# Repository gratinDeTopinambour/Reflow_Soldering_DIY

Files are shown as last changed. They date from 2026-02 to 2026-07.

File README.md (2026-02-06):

# Reflow Soldering DIY Controller

**Convert a standard consumer oven into a precise PCB reflow soldering station.**

This repository contains the complete electronics design, firmware, and mechanical files for a custom Reflow Oven Controller.The device is designed to precisely control a resistive heating element to follow the specific temperature profiles required for SMD soldering.

---

## 📂 Repository Structure

* **`Code/`**: Firmware source code for the STM32C0 microcontroller.
* **`Doc/`**: General project documentation and datasheets.
* **`Electronics/`**: Hardware design files, including the detailed technical rationale.
* **`3Dprint/`**: STL and CAD files for the controller enclosure.

---

## ⚡ System Overview

The controller operates as a closed-loop feedback system that regulates the temperature of a resistive heating element. 

### Key Technical Features
* **Power Control**: Designed for 220V / 50Hz mains up to **2400W** (12A design reference).
* **Switching Strategy**: Utilizes Zero-Crossing control to minimize EMI and power losses.
* **Galvanic Isolation**: Complete isolation between high-voltage AC and low-voltage logic via an Opto-TRIAC.
* **Microcontroller**: Powered by an **STM32C0 series** ARM Cortex-M0+.
* **User Interface**: Features an OLED display (128x64) and a 6-button navigation cluster.
* **Thermal Sensing**: Uses a glass-encapsulated NTC thermistor rated up to **300°C**.

---

## 🛠️ Hardware Specifications

The hardware design prioritizes low-cost, hand-solderable components and robust thermal management.

### Power Stage
| Component | Selection | Rationale |
| :--- | :--- | :--- |
| **TRIAC** | BTA16-600CW | 16A max current, snubberless design  |
| **Opto-TRIAC** | MOC3063M | Zero-crossing detection and safe isolation  |
| **Heatsink** | Boyd 530002B02500G | $2.6^{\circ}C/W$ resistance to handle ~13W dissipation  |

### Logic & Power
* **Input**: USB-C (5V).
* **Regulation**: L1117S33 LDO (SOT-223) provides a stable 3.3V rail for the MCU.
* **Optimization**: The temperature sensor uses an optimized $1.8k\Omega$ bridge resistor to maximize ADC voltage swing between $60^{\circ}C$ and $260^{\circ}C$.

---

## 🚀 Installation & Safety

### ⚠️ WARNING: High Voltage
This project involves **220V AC Mains**. Fatal injury or fire can occur if handled incorrectly. 
* Always ensure the device is unplugged before touching the electronics.
* Ensure the TRIAC heatsink is properly mounted as temperatures can reach $\approx 100^{\circ}C$ during operation.

### Setup
1. **Assembly**: Refer to the schematics in `Electronics/`. The design uses TSSOP-20 and SOT-223 packages for easy manual assembly.
2. **Firmware**: Flash the STM32C0 via the SWD interface pins (PA14/PA15).
3. **Calibration**: The system is tuned for a standard NTC thermistor (NRBG105F3950B1F).

---

## 👤 Author
**Valentin LEFEBVRE** (@topinambour)  
*Document Date: 06/02/2026*

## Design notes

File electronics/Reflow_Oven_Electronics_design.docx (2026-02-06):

Reflow-Oven Controller

Electronics design

LEFEBVRE Valentin, @topinambour

06/02/2026

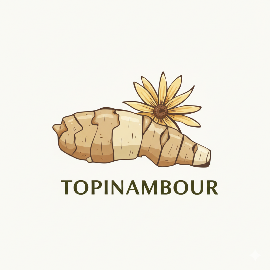
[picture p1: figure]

# 1 Introduction

The purpose of this document is to detail the electronics design, component selection, and calculations for a custom Reflow Oven Controller board.

This device is designed to convert a standard consumer oven into a PCB reflow soldering station. The main objective is to precisely control the oven's heating element to follow a specific temperature profile required for soldering surface-mount components. The controller manages the AC mains power to the heater, monitors the internal temperature in real-time, and provides a user interface for operation and status monitoring.

# 2 System Overview

## 2.1 Functional Description

The Reflow Oven Controller operates as a closed-loop feedback system that regulates the temperature of a resistive heating element.

Power Control: The system controls the AC mains power (220V, 50Hz) delivered to the oven's heater. Instead of complex phase-angle control, the system utilizes a simple on/off control scheme (Zero-Crossing), which is sufficient due to the high thermal inertia of the oven.

Isolation & Safety: To ensure safety and protect the low-voltage logic, a TRIAC is used to switch the load, driven by an Opto-TRIAC to provide galvanic isolation between the microcontroller and the high-voltage mains.

Central Processing: An STM32C0 series microcontroller acts as the brain of the system. It reads the temperature sensor, processes the control logic, drives the solid-state switch, and manages the user interface.

Sensing: Temperature monitoring is achieved using a glass-encapsulated NTC thermistor capable of withstanding high temperatures (up to 300°C) placed inside the oven.

User Interface: The operator interacts with the device through an OLED display and a set of push-buttons, allowing for profile selection and visual feedback during the reflow process.

Power Supply: The logic circuitry is powered via a USB-C connector (5V), which is regulated down to 3.3V to supply the microcontroller and peripherals.

## 2.2 Block Diagram

Oven

AC Power command

STM32C0

Temp sensor

Power input

User Interface

Oled display

Push button

Main AC

## 2.3 Main Design Requirements

The hardware design is driven by the following key electrical and environmental requirements:

AC Mains Compatibility: The device must operate on a 220V / 50Hz mains supply.

Load Capacity: The power stage must handle ovens rated up to 2400 W, requiring a design reference current of approximately 12 A.

Thermal Environment: Electronic components, particularly the power stage, must be rated to operate reliably within an enclosure ambient temperature of 50°C.

Galvanic Isolation: There must be complete isolation between the AC mains and the user-accessible logic/interface section.

EMI Reduction: Switching must occur at the AC zero-crossing point to minimize electromagnetic interference (EMI) and power losses.

Low Voltage Supply: The board must be powered by a standard USB-C connection (5V) and internally regulated to 3.3V for logic operation.

Cost & Assembly: The design prioritizes low-cost components and packages suitable for hand-soldering (e.g., TSSOP-20 for the MCU, SOT-223 for the LDO).

Temperature Range: The sensing subsystem must accurately measure temperatures from ambient (~15°C) up to the reflow peak of 260°C.

# 3 Heater power control

The main objective is to switch the oven on and off for use as a reflow oven. A TRIAC will be used to control the mains power to the oven, and an opto‑TRIAC driver will provide galvanic isolation between the microcontroller and the AC mains. Due to the thermal inertia of the oven, precise phase-angle control is not required. Simple on/off control is sufficient. To minimize unnecessary power losses and reduce EMI, a zero‑crossing opto‑TRIAC is used (at 50 Hz, the mains voltage crosses zero every 10 ms).

We will design the board for ovens up to 2400 W on a 220 V / 50 Hz mains supply.

The corresponding RMS current is:
- (2400 W)/(220V) ≈ 10.9 A
- Adding a 5% margin gives 11.45 A, so we will use 12 A as the design reference current.

## 3.1 Triac

To select a suitable TRIAC, we use ST’s ACS/TRIAC selection and simulation tool: https://eds.st.com/acswitch/#/

The simulator is configured with the following parameters:
- Nominal input voltage: 230 V
- Output RMS current: 12 A
- Load type: Heater
- Gate control: Isolated, phototriac

The Simulator give us the following schematics:

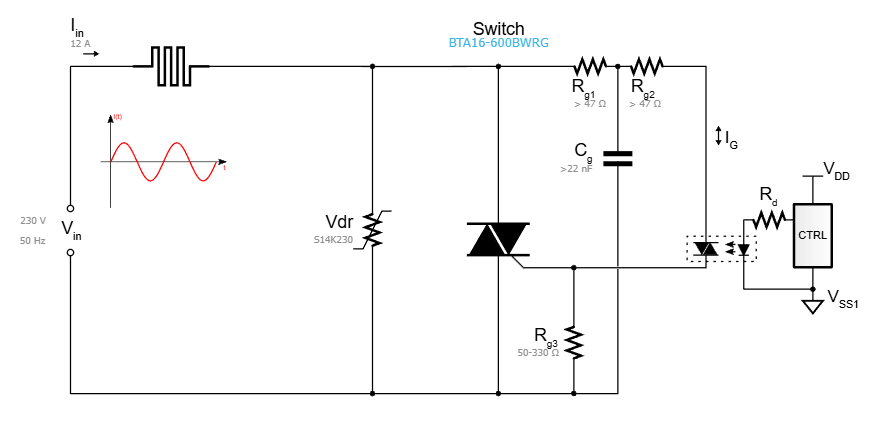
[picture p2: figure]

Figure 1: Heater Power Control ST Schematics

From the list of TRIACs suggested by ST, we will select the device with the lowest power dissipation. However, before making a final choice, we must refine the simulation parameters: 12 ARMS is too high to handle without an adequate heatsink.

In the ST simulator, under the heatsink selection options, we choose “Case in Environment” and set the environment temperature to 50 °C (estimated internal temperature inside a closed enclosure).

With these conditions, the BTA16-600CW appears to be a good candidate:
- IRMS max: 16 A
- VDRM/ VRRM: 600 V

From the datasheet, in Figure 2: “Maximum power dissipation versus on‑state RMS current (full cycle)”, the expected power dissipation at 12 ARMS is approximately 13W.

## 3.2 Heatsink

To dissipate these 13 W, we need a heatsink such that the total thermal resistance keeps the TRIAC junction below its maximum temperature. The required heatsink thermal resistance Rth(sa) can be calculated with:

P=((Tjmax-Ta))/(Rth(jc)+Rth(cs)+Rth(sa))

From the datasheet and our assumptions:
-Rth(jc) = 2.1°C/W
-Tjmax = 125°C.
-Ta = 50°C (temperature inside the box)
-Rth(cs) = 0.5°C/W

Rth(sa)=((Tjmax-Ta))/P- Rth(jc)-Rth(cs)= ((125-50))/13- 2.1-0.5=3.17°C/W

To safely dissipate 13 W at a 50°C ambient temperature inside the enclosure, we will need a heatsink with a thermal resistance of 3.17 °C/W or lower (the lower the value, the more effective the heatsink).

We will choose Heatsink 530002B02500G from BOYD for our design

The heatsink 530002B02500G from BOYD has a thermal resistance of 2.6 °C/W. At 14 W, it will cause a temperature rise of about 50°C (see thermal graph from datasheet) above the ambient temperature inside the box. With Ta = 50 °C, the heatsink temperature will be approximately 100°C, and the TRIAC junction will remain below its maximum 125 °C limit, ensuring safe operation.

## 3.3 OptoTriac

The opto‑triac is driven directly by the STM32 GPIO (3.3 V maximum I/O voltage).
A zero‑crossing device is required for reliable operation on 220 V rms mains.
The MOC3063, a widely used zero‑crossing opto‑triac, satisfies these requirements and is used in this design.

Emitter side
- Forward voltage (Vf) minimum: 0.7 V at Ift ≈ 0.1 mA
- Series resistor: 150 Ω from the 3.3 V GPIO to the LED

Power dissipation in the LED:
Pemitter = ((3.3 – Vf_min)²)/150= ((3.3 – 0.7)²)/150 ≈ 48 mW

Assuming an ambient temperature Ta = 50 °C and an LED thermal resistance giving a power‑to‑temperature factor of 0.00141 W/°C, the junction temperature is:
Tj_(emitter) = Ta + (Pemitter)/0.00141=50°C+ 0.048/0.00141=84°C

Detector side
The driven power triac is a BTA16CW, with a maximum gate trigger current of 25 mA.
At this current, the voltage across the opto‑triac output is:
Vtm(max at 25 mA) = 1.8 V

Power dissipation in the detector:
Pdetector = Vtm × Igate =1.8 V × 25 mA ≈ 45 mW

With an ambient temperature Ta = 50 °C and a power‑to‑temperature factor of 0.00176 W/°C for the detector section, the junction temperature is:

Tj_(detector) = Ta + (Pdetector)/0.00176=50°C+ 0.045/0.00176=76°C

Both the emitter and detector junction temperatures remain well within the safe operating range for the MOC3063 under the specified conditions.

## 3.4 Passive Components

The BTA16 is a snubberless Triac, and the load will not produce enough noise to cause issues. We can therefore simplify the design as follows.

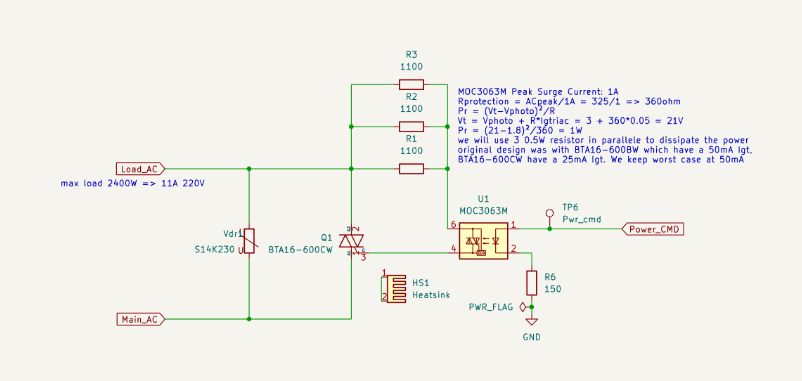
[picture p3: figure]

The resistor between the triac and the optotriac is designed to protect the optotriac from current surges. The MOC3063M can withstand up to 1 A of peak current.

We calculate the minimum resistance as:

R=(230*√2)/1=325ohm

We therefore need R > 325x1,05 = 341ohm. The closest standard value in the E24 series is 360ohm

Now we calculate the maximum power dissipated in the resistor:

Vtriacmax = R*Igatemax + Vphotomax = 360*0,025 + 3 = 12V

Pres = ((Vtriacmax – Vphotomin )²)/R=((12-0)²)/360= 0.4W

To be on the safe side. We will use three 1.1 kΩ, 0.5 W resistors in parallel to dissipate the power.

Recomputing for the worst-case scenario:

Iphotomax=(230*√2)/((R*0,95)/3)=0,934mA

Presmax= (Vtriacmax²)/((R*0,95)/3)=0.41W

This satisfies:

Iphoto < 1A

Pres/3 <0,5W

So, three 1.1 kΩ, 0.5 W resistors in parallel are sufficient for this design.

## 3.5 Command resistor

The STM32 microcontroller GPIO outputs 3.3 V with a maximum current of 20 mA.

The MOC3063M LED has a maximum trigger current of 5 mA.

Based on Figure 3: LED Forward Voltage vs. Forward Current from MOC3063M datasheet

- For 5 mA Vfmax = 1.25V

- For 20 mA, Vfmin = 1.1V

Series resistor calculation:

Rmin=(1,1V)/(20mA)=55ohm

Rmax=(1,25V)/(5mA)=250ohm

We will use R = 150ohm, as this value is already used multiple times in our design.

With R = 150ohm, the worst‑case current is:

If=(3,3V*0,95-1,5V)/(150*1,05)=10mA>5mA

This ensures reliable triggering of the MOC3063M while staying within the STM32 GPIO current capability.

# 4 Microcontroller

## 4.1 Microcontroller selection

The microcontroller is responsible for managing the user interface, temperature measurement, and control of the oven power stage. The following constraints and requirements drove the selection:

Electrical and System Constraints

Supply voltage:
- The board is powered from a USB‑C connector.
- A linear regulator (LDO) is used to stabilize the input voltage.
- The microcontroller must operate from a regulated supply below 5 V (nominally 3.3 V).

Required peripherals and I/Os:
- 6 digital inputs for the user interface:
- 1 I²C interface for the OLED display
- 1 analog input for temperature measurement
- 1 digital output for power control

In summary, the microcontroller must provide at least:
- VCC < 5 V
- 6 GPIO inputs
- 1 GPIO output
- 1 I²C bus
- 1 ADC channel

Package and Assembly Constraints

Since the board is intended to be assembled without a reflow oven in the first iterations, ease of hand‑soldering is a key criterion:

Preferred package: TSSOP, which offers:
- Sufficient pin pitch for manual soldering
- Good balance between pin count and PCB area

Minimum pin count: at least 10 pins are required (6 inputs + 1 output + I²C + analog input + supply/ground), so TSSOP‑8 is not suitable.

Given these constraints, TSSOP‑20 devices are a good fit: they are widely available, easy to solder by hand, and provide sufficient I/O and peripherals.

Technology and Cost Considerations

Several MCU families were considered:

Arduino‑style MCUs (e.g., ATmega328P):
- Operate at 5 V and are well known.
- However, they are relatively expensive for this application.

ESP32 / Wi‑Fi‑capable MCUs:
- Provide significantly more performance and peripherals than needed.
- Higher power consumption and unnecessary complexity for this design.

STM32 family (32‑bit ARM Cortex‑M):
- Low cost, especially in the low‑end series.
- Good availability of small packages such as TSSOP‑20.
- Familiar toolchain and ecosystem from previous projects.

Given prior experience with STM32 and their cost/performance ratio, an STM32 device was chosen.

Candidate Microcontrollers

Two pin‑compatible STM32 devices were identified as suitable candidates:
- STM32C011F6P6
- STM32C031F6P6

Common features relevant to this design:
- Supply voltage compatible with the regulated USB‑derived rail (< 5 V).
- TSSOP‑20 package, suitable for hand soldering.
- Sufficient GPIOs to handle:
- 6 push‑button inputs
- 1 digital output for MOC3063M control
- I²C interface for the OLED display
- 1 ADC channel for the thermistor

The main difference between the two devices is available RAM:
- STM32C011F6P6: 6 KB RAM
- STM32C031F6P6: 12 KB RAM

The OLED display has a resolution of 128 × 64 pixels, corresponding to 8192 bits (1024 bytes) for a full framebuffer. Depending on the graphics library and implementation, a significant portion of RAM may be needed to store display buffers, fonts, and temporary data structures.

Because the firmware will be developed after the hardware design, the exact RAM requirement is not fully defined at this stage. To keep flexibility the PCB will be designed to accept either STM32C011F6P6 or STM32C031F6P6 (same pinout/package).

During firmware development, memory usage will be evaluated:

- If 6 KB RAM is sufficient, the STM32C011 can be used, minimizing cost.
- If additional memory is required (e.g., for more complex UI or buffering), the STM32C031 will be assembled instead.

Final Choice

The design supports both STM32C011F6P6 and STM32C031F6P6 in TSSOP‑20 package. The STM32C0 series meets all functional, electrical, and packaging constraints while remaining low cost and easy to assemble by hand. The final MCU variant (C011 vs. C031) will be selected based on actual RAM requirements determined during firmware development.

## 4.2 STM32C0 implementation

The microcontroller used is from the STM32C0 series in a TSSOP‑20 package. Pin usage follows the recommendations from the STM32C0 datasheet and is tailored to the application’s I/O, analog, and communication requirements.

Reserved and Special‑Function Pins
PF2 – NRST:
- Used as the global reset input for the MCU.
- A 10 kΩ pull‑up resistor to VCC is added to prevent unintended resets due to noise.
- A momentary push‑button connects NRST to GND to allow manual reset.
- A 100 nF capacitor is connected between NRST and GND, as recommended in the datasheet, to improve noise immunity.

PA14 – BOOT0:
- Used to select the boot mode (normal user flash vs. system bootloader).
- The default state is normal user flash boot:
- A 10 kΩ pull‑down resistor to GND ensures BOOT0 is low during normal operation.
- A momentary push‑button connects BOOT0 to VCC when pressed, allowing the MCU to enter the bootloader if required.
- A 100 nF capacitor is placed between BOOT0 and GND as recommended, to avoid spurious boot mode changes due to noise.

PA14 / PA15 – SWD Interface:
- PA14: SWCLK
- PA15: SWDIO
- These pins are routed to a standard ST‑LINK SWD connector for programming and debugging.
- No other functions are assigned to these pins to ensure reliable SWD communication.

PC14 / PC15 – Oscillator Pins:
- Dedicated to an external low‑speed or high‑speed crystal/oscillator.
- For this design, no external oscillator is used. The internal oscillator of the STM32C0 is sufficient for the required timing accuracy.
- PC14 and PC15 are therefore left unconnected.

Functional Pin Mapping

The remaining pins are assigned as follows:
I²C interface (OLED display)
- PB6: I2C SCL
- PB7: I2C SDA

User push buttons (digital inputs)
- PA2: “Return” button
- PA3: “Valid” button
- PA4 – PA7: 4 directional buttons (cross pattern)

Temperature measurement (analog input)
- PA0: ADC input for the NTC thermistor.

Oven power control (digital output)
- PA8: Digital output driving the control input of the MOC3063M optotriac driver.

Status LEDs (digital outputs)
- PA9/PA10: LED output

This pin mapping was defined in STM32CubeIDE, ensuring all required peripherals (I²C, ADC, GPIO) are properly configured and that there are spare I/Os for debugging or future extensions.

Power Supply Decoupling

The MCU is powered from the regulated VCC rail derived from the USB‑C input via an LDO. According to the STM32C0 datasheet, local decoupling capacitors (100nF and 4.7uF) are required between VCC and GND (at the MCU pins):

# 5 Temperature sensor

## 5.1 Component selection

To monitor the temperature inside the oven, we considered two options:

Thermocouple
Thermocouples offer a very wide measurement range (approximately −200°C to 1000°C) and good accuracy, but they require dedicated front‑end electronics (amplifier, cold‑junction compensation, ADC), which increases both cost and design complexity.

Thermistor
Standard NTC thermistors are typically rated up to about 150°C, but glass‑encapsulated thermistors can operate up to roughly 300°C. They are inexpensive and can be read with a simple resistor divider connected to the microcontroller’s ADC input.

Given the target reflow profile (from ambient ≈15°C up to 260°C), and in order to minimize cost and complexity, we selected a glass NTC thermistor, reference NRBG105F3950B1F, specified from −40°C to 300°C.

Resistor Divider Design
The thermistor is used in a voltage divider to generate a temperature‑dependent voltage for the STM32 ADC:
Supply voltage: 3.3 V
One fixed resistor R
The NTC thermistor NRBG105F3950B1F

We want to choose R so that the ADC sees the widest possible voltage variation over the most relevant temperature range, which in our case is 60°C to 260°C (the useful reflow control region).

Vt=3.3V*R/(Rth1+R)

From the datasheet:
at 60°C Rth1 =24.75kohm
at 260°C Rth1 = 145ohm
we want |Vt60°C – Vt260°C| as high as possible

Max|Vt60-Vt260|=Max|3.3*R/(Rth60+R)-3.3*R/(Rth260+R)|

Max|(R(Rth260+R)-R(Rth60+R))/((Rth60+R)(Rth260+R))|=Max|(-R*Rth60)/(R^2 +(Rth60+Rth260)R+Rth60*Rth260)|

We look after the derivate in zero.

(-(Rth60-Rth260)*(R^2 +(Rth60+Rth260)R+Rth60*Rth260)+R24605(2R+(Rth60+Rth260)))/((R^2 +(Rth60+Rth260)R+Rth60*Rth260)^2)

(Rth60-Rth260)R^2 -(Rth60-Rth260)*Rth60*Rth260=0

R^2 =((Rth60-Rth260)*Rth60*Rth260)/((Rth60-Rth260))=Rth60*Rth260

R= √(Rth60*Rth260)=√3588750=1894ohm

From the optimization, the ideal bridge resistor value is approximately 1.894 kΩ. We will use a standard 1.80 kΩ, 0.1% resistor, which is the closest commonly available value.

At 60°C Vt = 0.22V

At 260°C Vt = 3.05V

This provides a large voltage swing at the STM32 ADC input.

# 6 User interface

The user interface includes:
- 6 push-buttons:
- 4 directional buttons (Up, Down, Left, Right)
- 1 “Valid” button
- 1 “Return” button
- 1 OLED display (I²C, 3.3 V)
- 2 status LEDs (Red and Green)

Buttons:
- Each button is connected between an STM32 GPIO and GND.
- Internal pull-up resistors of the STM32 are used.
- Logic: button released = logic high, button pressed = logic low.
- No external pull-up resistors are required.

OLED Display:
- Powered by 3.3 V from the on-board LDO.
- Connected to the STM32 via I²C (SCL, SDA).
- I²C pull-ups are configured inside the STM32.

Status LEDs:
- 2 LEDs (Red, Green), each in series with a 150 Ω resistor.
- Driven directly from STM32 GPIOs (no transistor needed).
- Current per LED is limited to about 10 mA, within STM32 GPIO limits (80 mA total).

# 7 Power regulator

This design uses a USB‑C connector as the main power input. To operate USB‑C in a simple “default power” sink mode (5 V supply), each CC pin must be pulled down to ground. We therefore connect a 5.1 kΩ (1%) resistor from:
- CC1 to GND
- CC2 to GND

The system logic operates at 3.3 V. Since the maximum current consumption is below 300 mA, a linear regulator (LDO) provides a simpler and adequate solution compared to a switching regulator (SMPS).

We selected the L1117S33 3.3 V LDO, commonly used on STM32 evaluation boards. Key characteristics:
- Input voltage: up to 15 V
- Fixed output: 3.3 V
- Typical dropout voltage: ~1 V
- Maximum output current: up to 800 mA

We use the SOT‑223 package because it is relatively easy to solder, it has a compact footprint and it can dissipate the required power with an appropriate copper thermal pad.

For the worst‑case calculation, we assume:
- Input voltage (including tolerance): 5 V × 1.05 = 5.25 V
- Output voltage (including tolerance): 3.235 V (worst‑case lower bound)
- Maximum load current: 300 mA

The power dissipated by the LDO is:

P= (5V*1.05-3.235V)*0.3A = 0.6W

Given the junction‑to‑ambient thermal resistance Rtja of 110 °C/W for the SOT‑223 package:

Tmax = Ta + Rtja*P = 50 + 110*0.6 = 116°C

With an ambient temperature of 50 °C, the junction temperature is estimated at about 116 °C, which remains below the maximum junction temperature Tjmax 125°C.

According to application note AN044_EN (Figure 11), a SOT‑223 package mounted on a PCB with a 100 mm² thermal pad can dissipate up to approximately 0.7 W. Our PCB layout includes a copper thermal pad larger than 100 mm², to maximize heat dissipation and provide additional safety margin.

The L1117 datasheet recommends:
- A 10 µF capacitor between the input pin and GND
- A 10 µF capacitor between the output pin and GND

These capacitors are placed as close as possible to the LDO pins to ensure stability and reduce noise on the 3.3 V rail.

A power indicator LED is connected between the 3.3 V output and GND through a 150 Ω series resistor. This LED provides a visual indication that the board is correctly powered and that the 3.3 V rail is present.

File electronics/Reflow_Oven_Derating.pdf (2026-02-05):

Reference | Value | Footprint | part | datasheet | Valid | Current (A) | Max Current (A) | Current_valid | Voltage (V) | Max Voltage (V) | Voltage_Valid | Power (W) | Max Power (W) | Power_valid | Temperature | Max temperature | Temp_valid
C1 100nF Capacitor_SMD:C_0805_2012Metric_Pad1.18x1.45mm_HandSolder C0805C104K5RACTU KEM_C1002_X7R_SMD.pdf | OK | | 3,365 50 | OK | | 50 125 | OK
C2 100nF Capacitor_SMD:C_0805_2012Metric_Pad1.18x1.45mm_HandSolder C0805C104K5RACTU KEM_C1002_X7R_SMD.pdf | OK | | 3,365 50 | OK | | 50 125 | OK
C3 100nF Capacitor_SMD:C_0805_2012Metric_Pad1.18x1.45mm_HandSolder C0805C104K5RACTU KEM_C1002_X7R_SMD.pdf | OK | | 3,365 50 | OK | | 50 125 | OK
C4 4.7uF Capacitor_SMD:C_0805_2012Metric_Pad1.18x1.45mm_HandSolder C0805C475K3RACTU KEM_C1002_X7R_SMD.pdf | OK | | 3,365 25 | OK | | 50 125 | OK
C5 10uF Capacitor_SMD:C_0805_2012Metric_Pad1.18x1.45mm_HandSolder C0805C106K3PACTU KEM_C1006_X5R_SMD.pdf | OK | | 5,25 25 | OK | | 50 85 | OK
C6 10uF Capacitor_SMD:C_0805_2012Metric_Pad1.18x1.45mm_HandSolder C0805C106K3PACTU KEM_C1006_X5R_SMD.pdf | OK | | 3,365 25 | OK | | 50 85 | OK
C7 100nF Capacitor_SMD:C_0805_2012Metric_Pad1.18x1.45mm_HandSolder C0805C104K5RACTU KEM_C1002_X7R_SMD.pdf | OK | | 3,365 50 | OK | | 50 125 | OK
D1 RED_LED LED_THT:LED_D5.0mm | OK
D2 GREEN_LED LED_THT:LED_D5.0mm | OK
QTLP650C4TR/FC15-DSE-0031723-QTLP650C4TR-FC15-D3 POWER_LED LED_SMD:LED_1206_3216Metric_Pad1.42x1.75mm_HandSolder 21SYGC/S530-E2/TR8 21SYGC-S530-E2-TR8 -V1.pdf | OK | 0,011212121 0,015 | OK | 3,365 5 | OK | 0,037728788 0,06 | OK | 50 85 | OK
HS1 HEAT_SINK 530002B02500G 530002B02500G Boyd-Board-Level-Heatsinks-Catalog.pdf | OK | | | | | | | 100 150 | OK
HP HEAT_PASTE -TC3-1G TC3-1G.pdf | OK | | | | | | | 100 150 | OK
J1 Conn_01x04_Pin Connector_PinHeader_2.54mm:PinHeader_1x04_P2.54mm_Vertical | OK
J2 OLED_Display Connector_PinHeader_2.54mm:PinHeader_1x04_P2.54mm_Vertical oled display ruizhi 0.96 OLED_096.pdf | OK | | | 3,365 5,2 | OK | | | 50 80 | OK
J3 USB_C_Receptacle_PowerOnly_6P Connector_USB:USB_C_Receptacle_GCT_USB4125-xx-x-0190_6P_TopMnt_Horizontal USB4125-GF-A usb4125-spec.pdf | OK | 0,80207962 3 | OK | 5,25 48 | OK | | | 50 85 | OK
Q1 BTA16-600CW Package_TO_SOT_THT:TO-220-3_Vertical BTA16-600CWRG bta16.pdf | OK | 12 16 | OK | 325,2691193 600 | OK | 13 14,42307692 | OK | 117,6 125 | OK
R1 1100ohm Resistor_THT:R_Axial_DIN0309_L9.0mm_D3.2mm_P12.70mm_Horizontal CFR-50JB-52-1K1 YAGEO-CFR_DATASHEET.pdf | OK | | | 230 300 | OK | 0,308611111 0,5 | OK | 50 70 | OK
R2 1100ohm Resistor_THT:R_Axial_DIN0309_L9.0mm_D3.2mm_P12.70mm_Horizontal CFR-50JB-52-1K1 YAGEO-CFR_DATASHEET.pdf | OK | | | 230 300 | OK | 0,308611111 0,5 | OK | 50 70 | OK
R3 1100ohm Resistor_THT:R_Axial_DIN0309_L9.0mm_D3.2mm_P12.70mm_Horizontal CFR-50JB-52-1K1 YAGEO-CFR_DATASHEET.pdf | OK | | | 230 300 | OK | 0,308611111 0,5 | OK | 50 70 | OK
R4 1800ohm Resistor_SMD:R_0805_2012Metric_Pad1.20x1.40mm_HandSolder ERA-6AEB182V R1800_panasonic.pdf | OK | | | 3,365 100 | OK | 0,006296978 0,125 | OK | 50 85 | OK
R5 150ohm Resistor_SMD:R_0805_2012Metric_Pad1.20x1.40mm_HandSolder CRCW0805150RFKEA resistor_vishay.pdf | OK | | | 3,365 150 | OK | 0,076250673 0,25 | OK | 50 70 | OK
R6 150ohm Resistor_SMD:R_0805_2012Metric_Pad1.20x1.40mm_HandSolder CRCW0805150RFKEA resistor_vishay.pdf | OK | | | 3,365 150 | OK | 0,076250673 0,25 | OK | 50 70 | OK
R7 150ohm Resistor_SMD:R_0805_2012Metric_Pad1.20x1.40mm_HandSolder CRCW0805150RFKEA resistor_vishay.pdf | OK | | | 3,365 150 | OK | 0,076250673 0,25 | OK | 50 70 | OK
R12 150ohm Resistor_SMD:R_0805_2012Metric_Pad1.20x1.40mm_HandSolder CRCW0805150RFKEA resistor_vishay.pdf | OK | | | 3,365 150 | OK | 0,076250673 0,25 | OK | 50 70 | OK
R8 10kohm Resistor_SMD:R_0805_2012Metric_Pad1.20x1.40mm_HandSolder CRCW080510K0FKEA resistor_vishay.pdf | OK | | | 3,365 150 | OK | 0,00114376 0,25 | OK | 50 70 | OK
R9 10kohm Resistor_SMD:R_0805_2012Metric_Pad1.20x1.40mm_HandSolder CRCW080510K0FKEA resistor_vishay.pdf | OK | | | 3,365 150 | OK | 0,00114376 0,25 | OK | 50 70 | OK
R10 5.1kohm Resistor_SMD:R_0805_2012Metric_Pad1.20x1.40mm_HandSolder CRCW08055K10FKEA resistor_vishay.pdf | OK | | | 5,25 150 | OK | 0,005459002 0,25 | OK | 50 70 | OK
R11 5.1kohm Resistor_SMD:R_0805_2012Metric_Pad1.20x1.40mm_HandSolder CRCW08055K10FKEA resistor_vishay.pdf | OK | | | 5,25 150 | OK | 0,005459002 0,25 | OK | 50 70 | OK
SW1 Valid Button_Switch_THT:SW_PUSH_6mm_H5mm | OK
SW2 Up Button_Switch_THT:SW_PUSH_6mm_H5mm | OK
SW3 Down Button_Switch_THT:SW_PUSH_6mm_H5mm | OK
SW4 Left Button_Switch_THT:SW_PUSH_6mm_H5mm | OK
SW5 Right Button_Switch_THT:SW_PUSH_6mm_H5mm | OK
SW6 return Button_Switch_THT:SW_PUSH_6mm_H5mm | OK
SW7 NRST Button_Switch_THT:SW_PUSH_6mm_H5mm | OK
SW8 BOOT0 Button_Switch_THT:SW_PUSH_6mm_H5mm | OK
eaton-nrbg-glass-sealed-radial-lead-ntc-TH1 Thermistor_NTC Resistor_THT:R_Axial_DIN0204_L3.6mm_D1.6mm_P2.54mm_Vertical NRBG105F3950B1F thermistor-datasheet-elx1105-en.pdf | OK | | | 3,365 50 | OK | 0,000233092 0,032 | OK | 260 300 | OK
U1_emitter MOC3063M Package_DIP:DIP-6_W7.62mm_LongPads MOC3063M MOC3163M-D.pdf | OK | 0,017946128 0,06 | OK | 3,365 6 | OK | 0,017946128 0,04935 | OK | 62,72775032 100 | OK
U1_detector MOC3063M Package_DIP:DIP-6_W7.62mm_LongPads MOC3063M MOC3163M-D.pdf | OK | 0,89605818 1 | OK | 325,2691193 600 | OK | 0,045 0,0616 | OK | 75,56818182 100 | OK
U2 STM32C011F6Px Package_SO:TSSOP-20_4.4x6.5mm_P0.65mm STM32C011F6P6 stm32c011f6.pdf | OK | 0,067979798 0,1 | OK | 3,365 4 | OK | | | 50 85 | OK
STM32C031F6Px Package_SO:TSSOP-20_4.4x6.5mm_P0.65mm STM32C031F6P6 stm32c031f6.pdf | OK | 0,067979798 0,1 | OK | 3,365 4 | OK | | | 50 85 | OK
U4 LD1117S33TR_SOT223 Package_TO_SOT_SMD:SOT-223-3_TabPin2 LD1117S33TR LD1117.pdf | OK | 0,155139073 0,8 | OK | 5,25 15 | OK | 0,312605232 12 | OK | 84,38657547 125 | OK
Vdr1 S14K230 Varistor:RV_Disc_D15.5mm_W7.5mm_P7.5mm B72214S0231K101 SIOV_Leaded_StandarD.pdf | OK | 12 3000 | OK | | | | | 50 105 | OK

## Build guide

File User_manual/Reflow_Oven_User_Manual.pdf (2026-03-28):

# Reflow-Oven Controller

User Manual

P a g e 1 | 7

P a g e 2 | 7

## Introduction

The purpose of this document is to explain how to use the reflow oven.

This device is designed to convert a standard consumer oven into a PCB reflow soldering station. The main objective is to precisely control the oven's heating element to follow a specific temperature profile required for soldering surface-mount components. The controller manages the AC mains power to the heater, monitors the internal temperature in real-time, and provides a user interface for operation and status monitoring.

P a g e 3 | 7

## Table of content

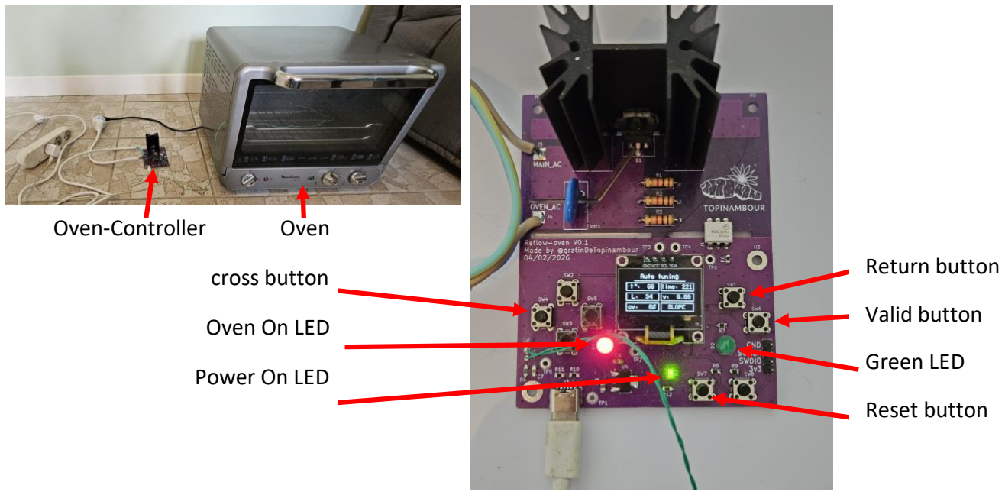
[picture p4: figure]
Oven-Controller; Oven; cross button; Oven On LED; Power On LED; Return button; Valid button; Green LED; Reset button
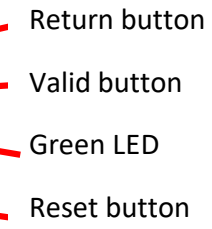
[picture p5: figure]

P a g e 4 | 7

## System Overview

### Functional Description

The Reflow Oven Controller operates with a regular mini oven.

Oven Controller: the Board that control the Oven

Oven: Any Oven that can go up to 240°C under 2400W (for 220V 50Hz main supplies only). You need a simple furnace without power-loss security (because the controller will switch on and off the main AC if the oven has a power loss safety the controller will not be able to turn it back on)

Cross button: Button used for navigation.

Oven On LED: This Red LED will turn on each time the Oven is switched on.

Power On LED: Green LED light on if the board is correctly powered through the 5V USB cable.

Return Button: Return to the previous menu.

Valid Button: Use this button to go to the next menu.

Green LED: switch on and off each second.

Reset Button: Reset the board.

### Power on

Cut the red wire of any electrical extension cord and solder each side of the cut wire to Main AC and Oven AC on the controller board.

Check that the BTA16 is correctly soldered to the board, and the heat sink is correctly placed with thermal paste.

P a g e 5 | 7

Connect a 5v USB cable to the board. The Power-on LED should light up, and the Green led should blink. If the screen is not turned on, press Reset.

Plug the Oven into the extension cord.

After this step the board will be connected to the main AC. DO NOT TOUCH ANY PART on the top side of the controller board.

Plug the extension board on main AC.

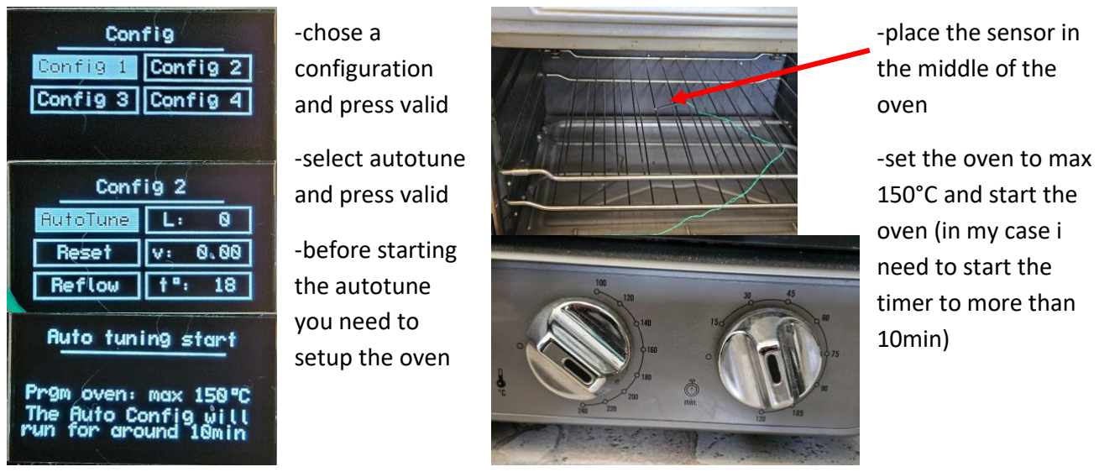
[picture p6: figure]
-place the sensor in the middle of the oven; -set the oven to max 150°C and start the oven (in my case i need to start the timer to more than 10min); -chose a configuration and press valid; -select autotune and press valid; -before starting the autotune you need to setup the oven
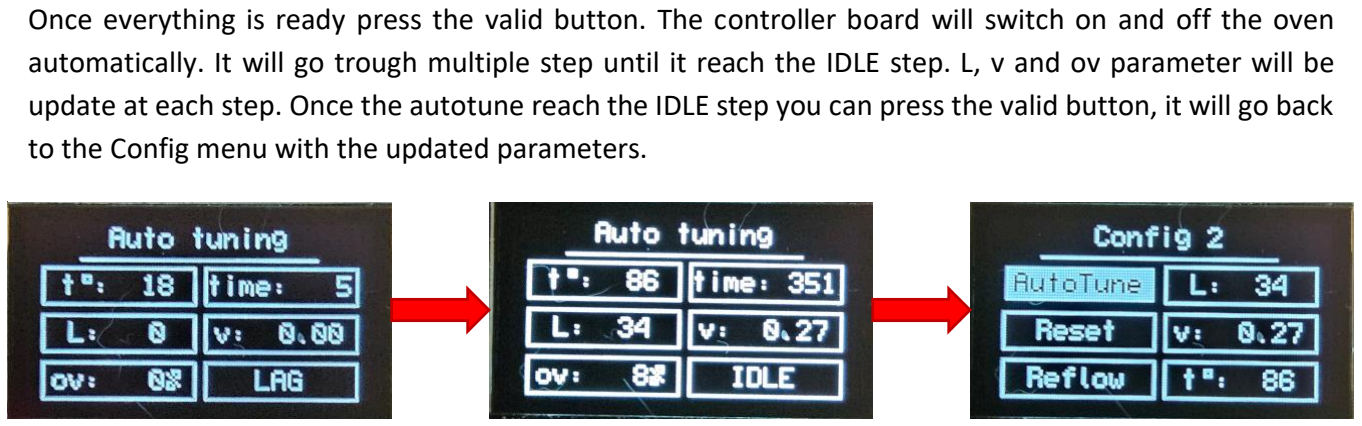
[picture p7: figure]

P a g e 6 | 7

## How to use

Once the display is on, press the valid button. You will be able to choose between 4 different configurations if you have multiple ovens or if you want to try some modifications. When using a new configuration all parameters are set to zero, you need to setup those values either by hand or with the autotune method, or else the controller will not be able to control the oven.

### Autotune

The autotune method takes around 10min. The controller will record the speed of the oven (v) the reaction time (L) and the overshoot (ov).

### Reflow

This version of the controller only works with low temp solder paste SN42BI58. Other pastes may be implemented later.

First, apply solder paste on all the top mount footprint components. Place the top mount component in their right place. A stencil is a great help to place solder paste, but you can place it by hand with precaution.

Place the populated board in the oven, over or as close as possible to the temperature sensor

Once everything is ready press the valid button. The controller board will switch on and off the oven automatically. It will go trough multiple step until it reach the IDLE step. L, v and ov parameter will be update at each step. Once the autotune reach the IDLE step you can press the valid button, it will go back to the Config menu with the updated parameters.

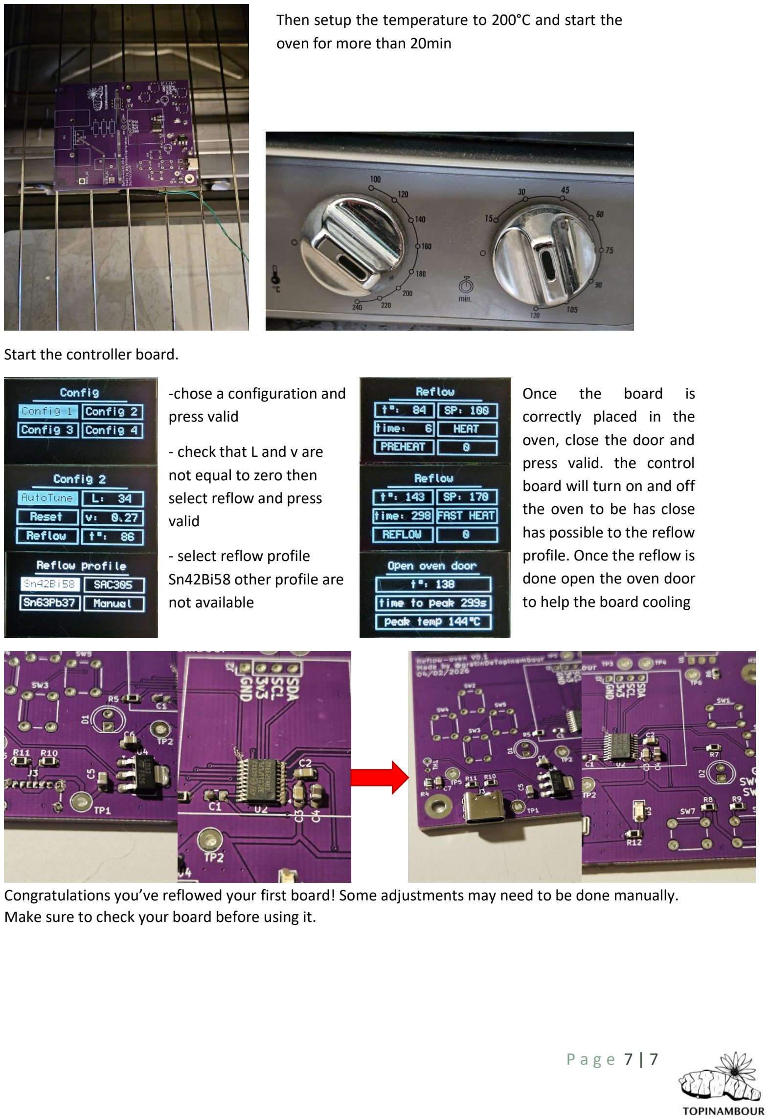
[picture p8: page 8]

P a g e 7 | 7

Start the controller board.

Congratulations you’ve reflowed your first board! Some adjustments may need to be done manually. Make sure to check your board before using it.

Then setup the temperature to 200°C and start the oven for more than 20min

-chose a configuration and press valid

- check that L and v are
not equal to zero then
select reflow and press
valid
- select reflow profile
Sn42Bi58 other profile are not available
Once | the | board | is
correctly placed in the
oven, close the door and
press valid. the control
board will turn on and off the oven to be has close
has possible to the reflow profile. Once the reflow is done open the oven door
to help the board cooling

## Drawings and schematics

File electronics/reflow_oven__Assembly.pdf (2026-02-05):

J3 R11 | R10 | R3 | SW8 U4 TP5 1 | 2 | 3 | 4 | 5 | 6 1 | 2 | 3 | 4 | 5 | 6 ABCD | ABCD Date: KiCad | E.D.A. 9.0.7 Size: A4 | Rev:

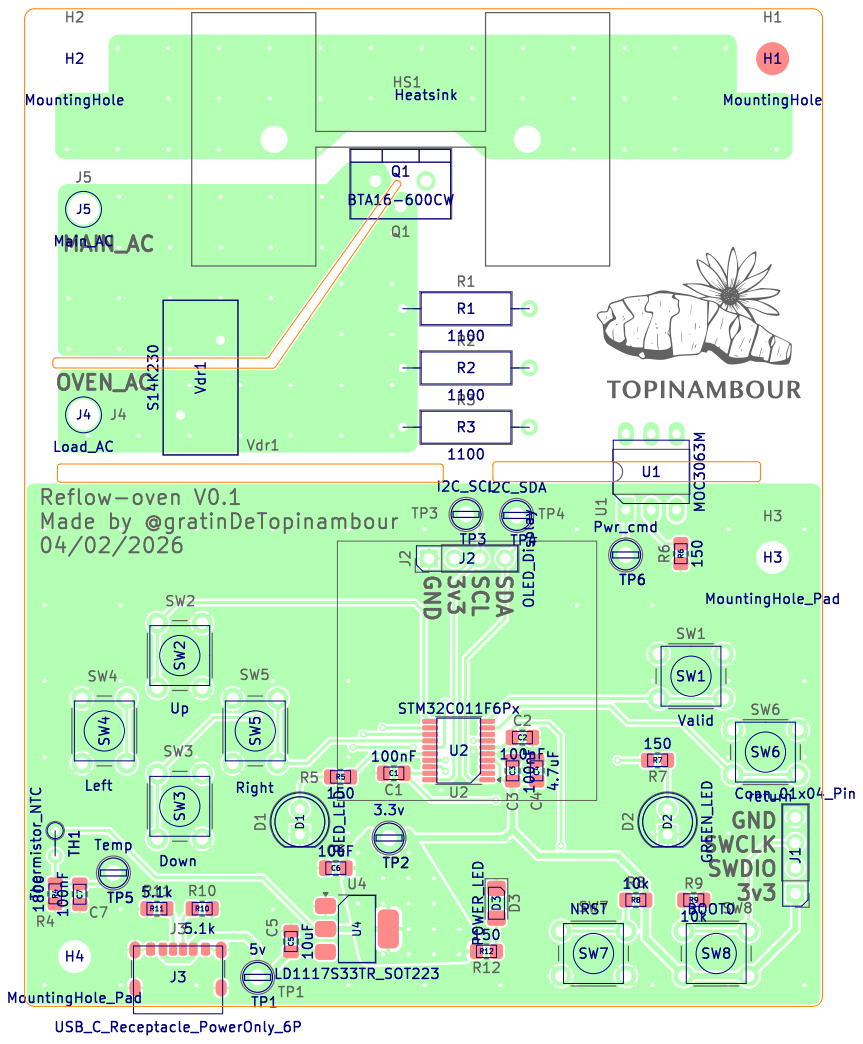
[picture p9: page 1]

1 | 2 | 3 | 4 | 5 | 6

A

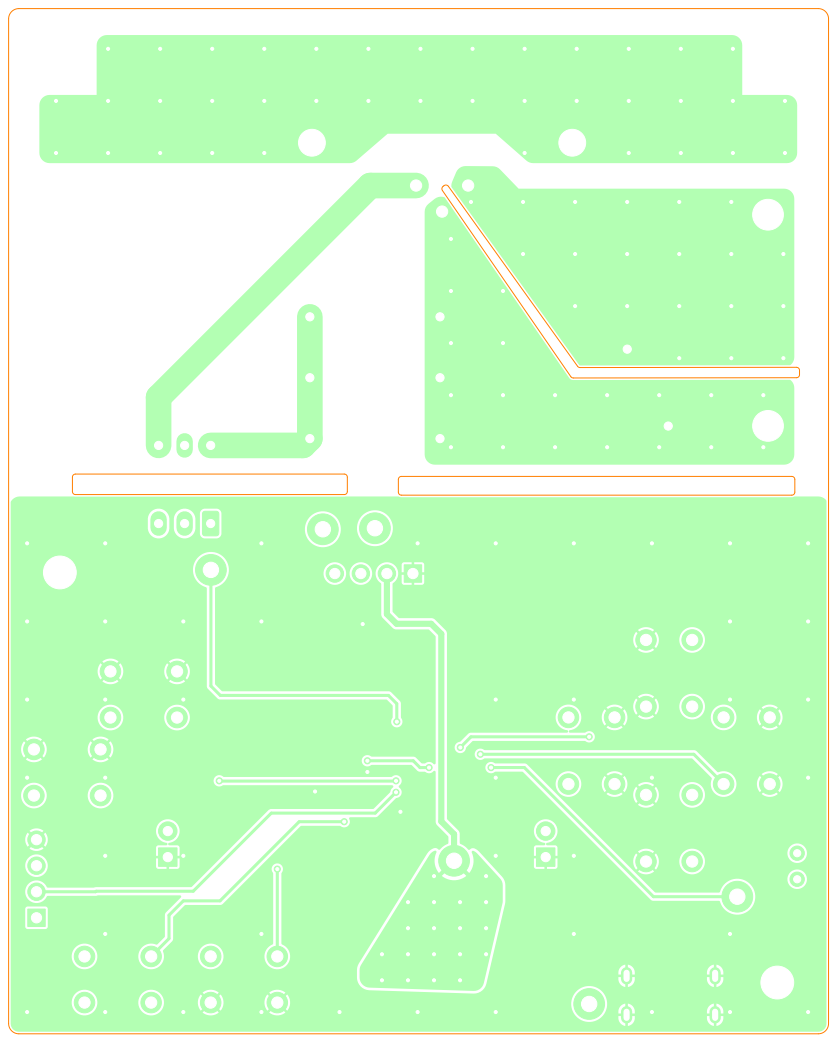
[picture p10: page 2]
D Date: KiCad; E.D.A. 9.0.7 Size: A4; Rev:; Id: /1 Title: File: reflow_oven.kicad_pcb Sheet: Colored; BOT Board2Pdf:; Colored; BOT -; Page 2/2

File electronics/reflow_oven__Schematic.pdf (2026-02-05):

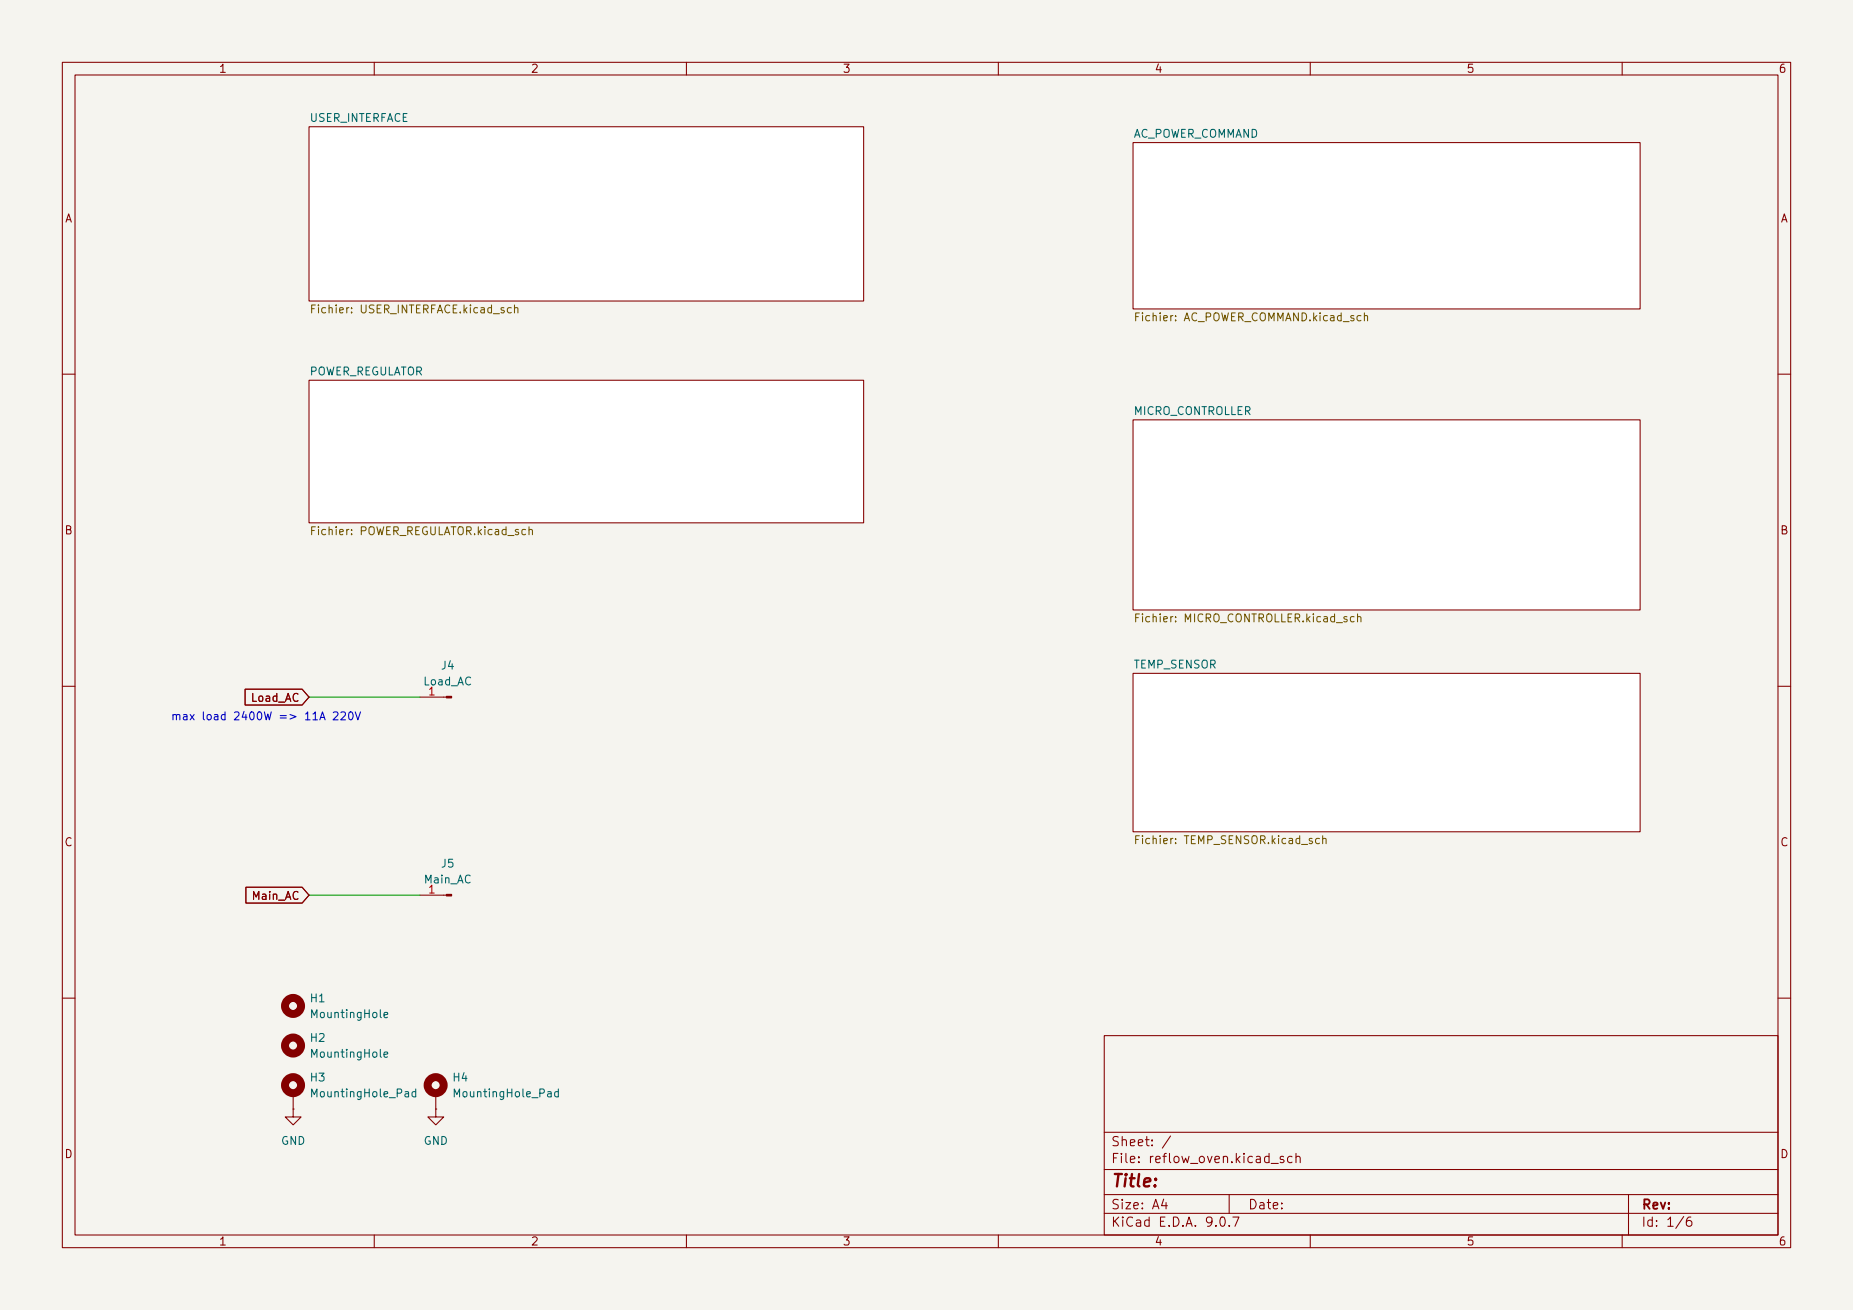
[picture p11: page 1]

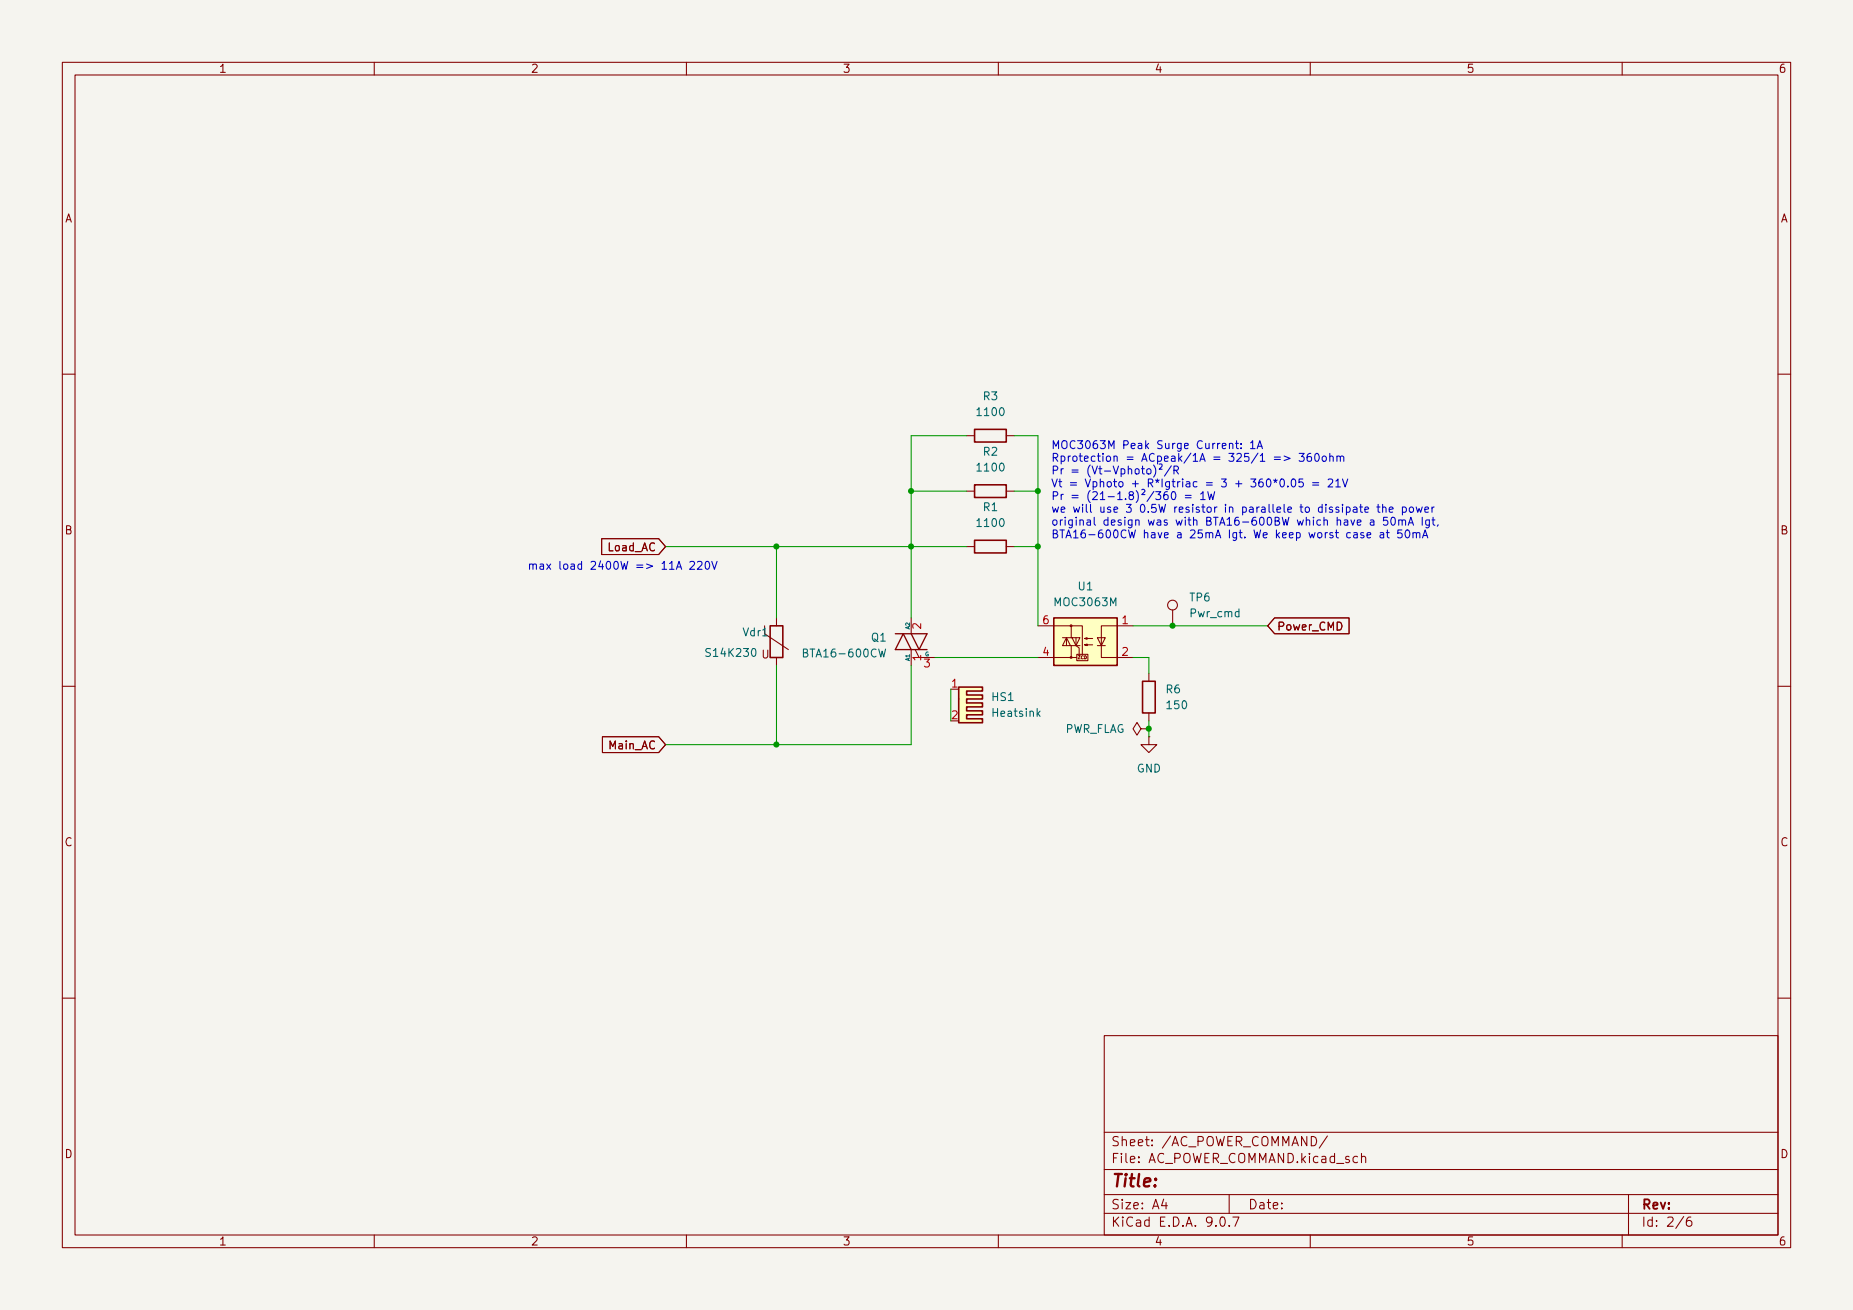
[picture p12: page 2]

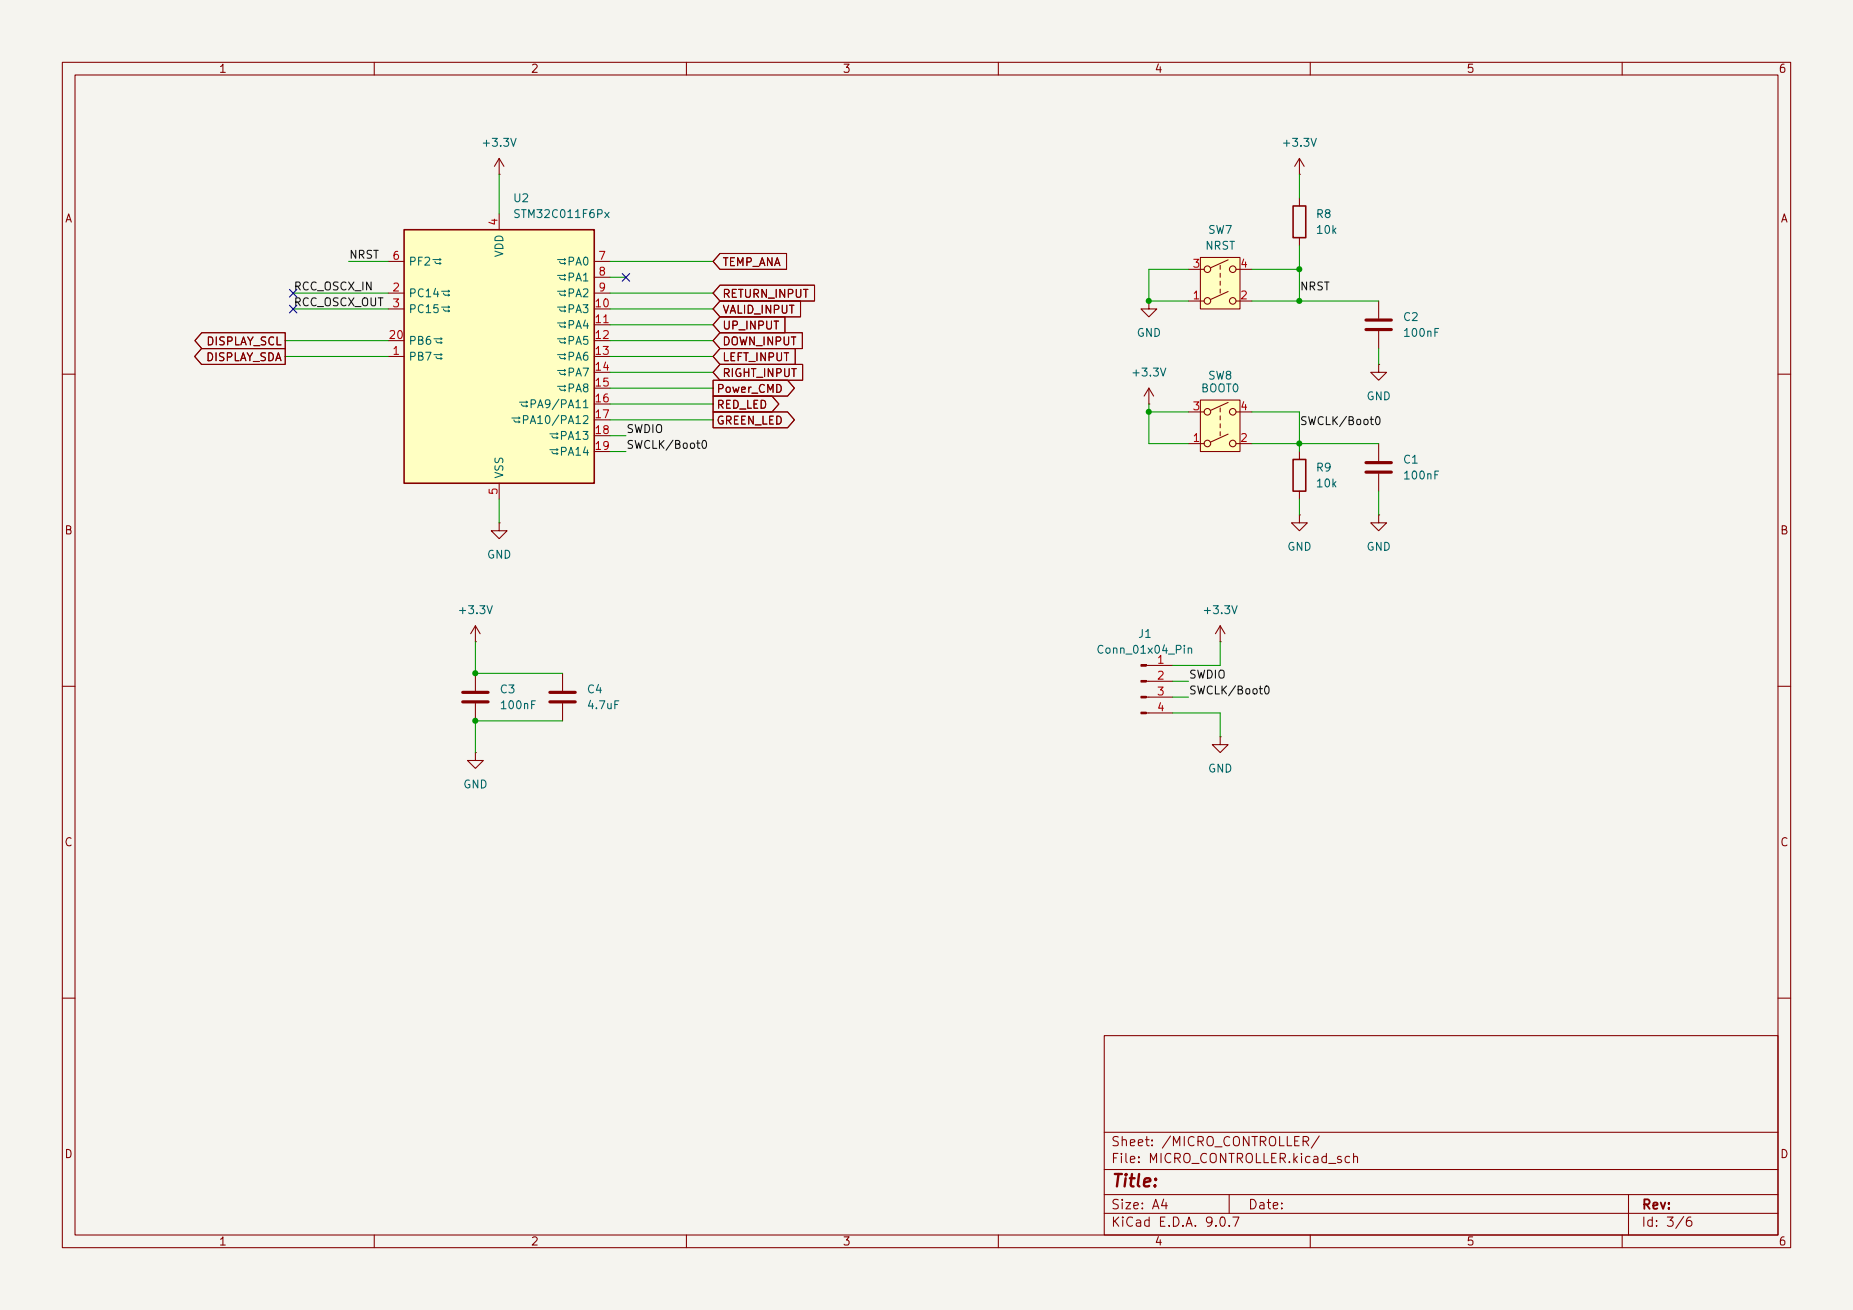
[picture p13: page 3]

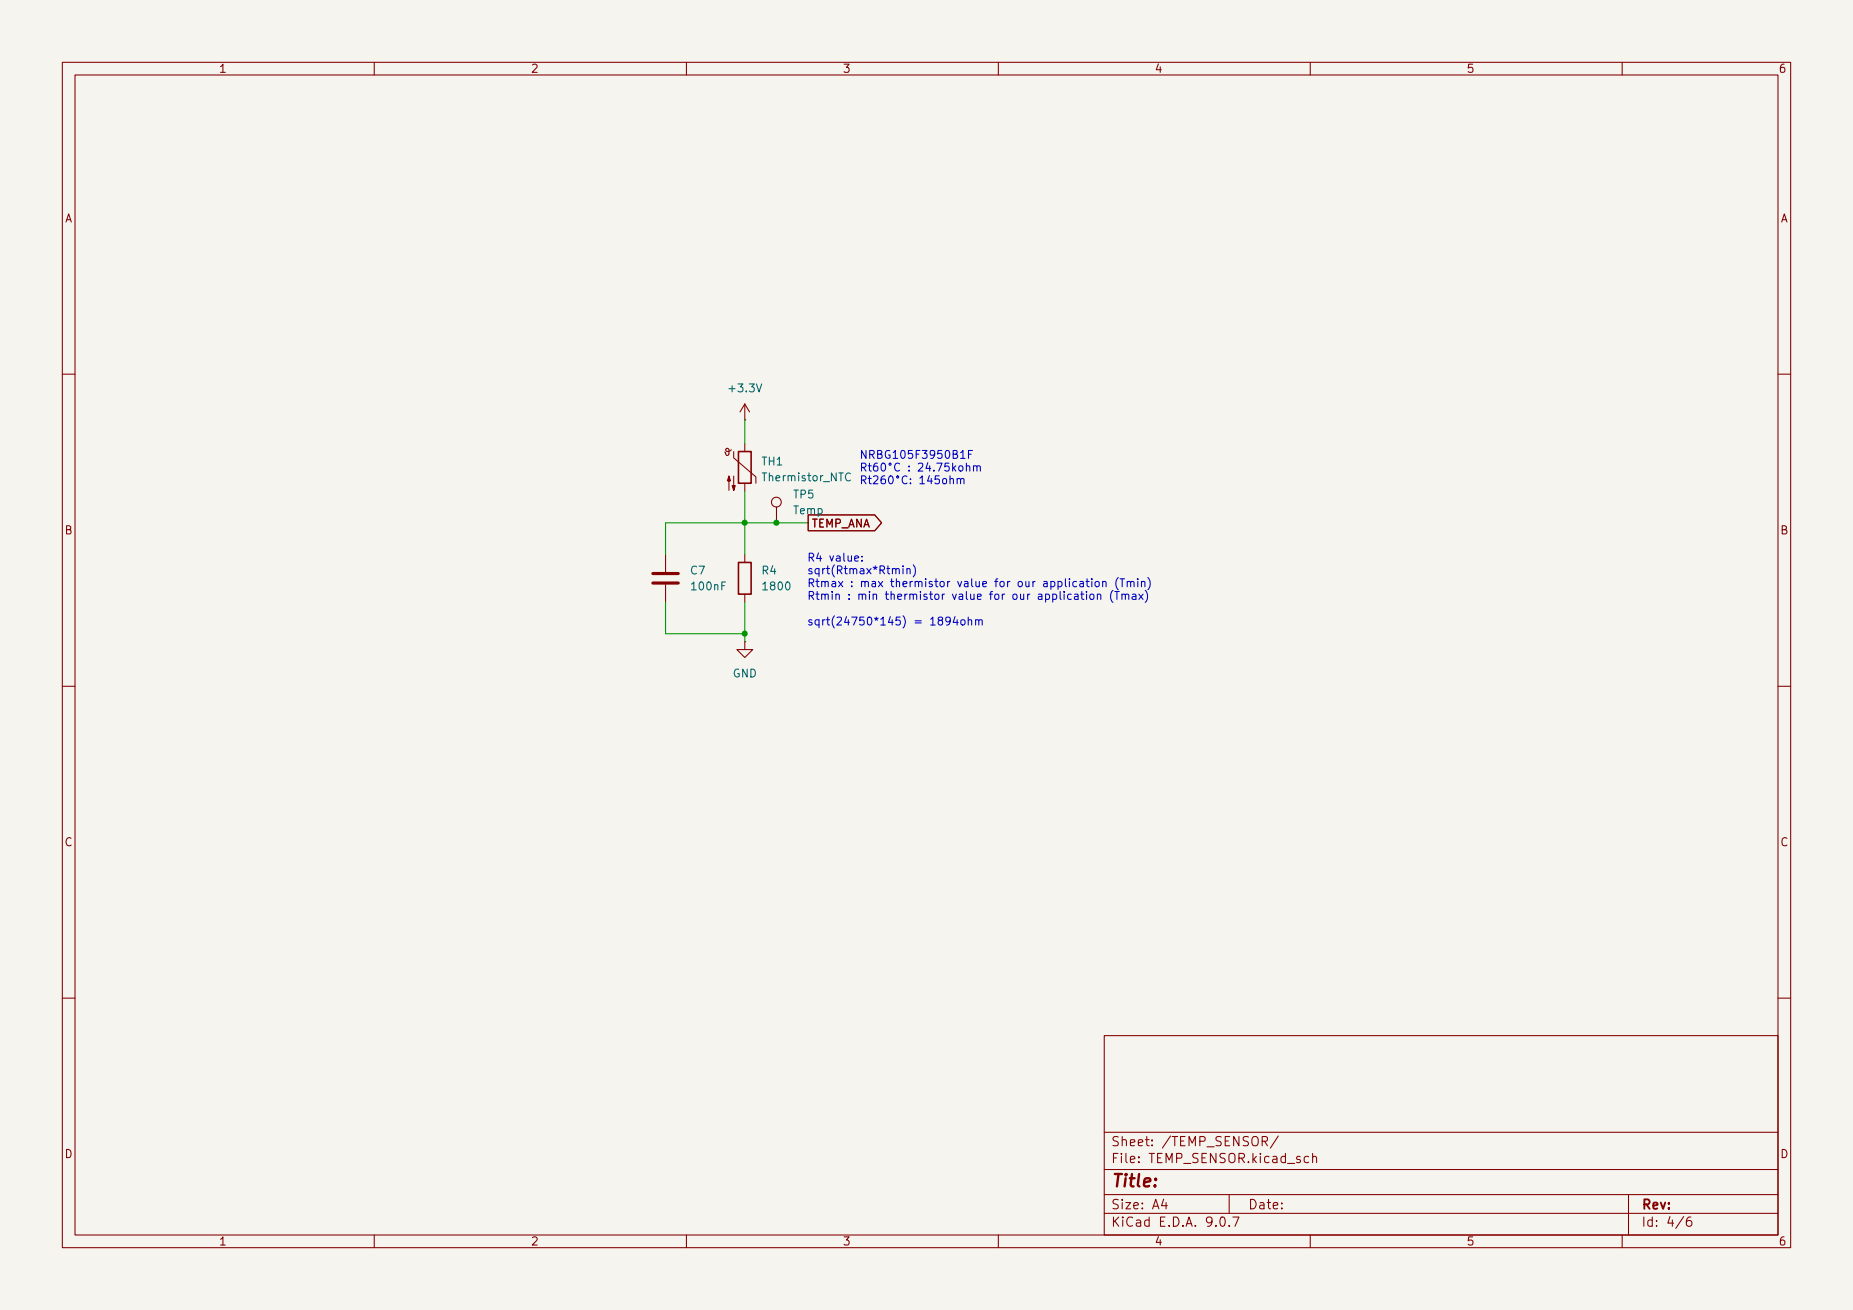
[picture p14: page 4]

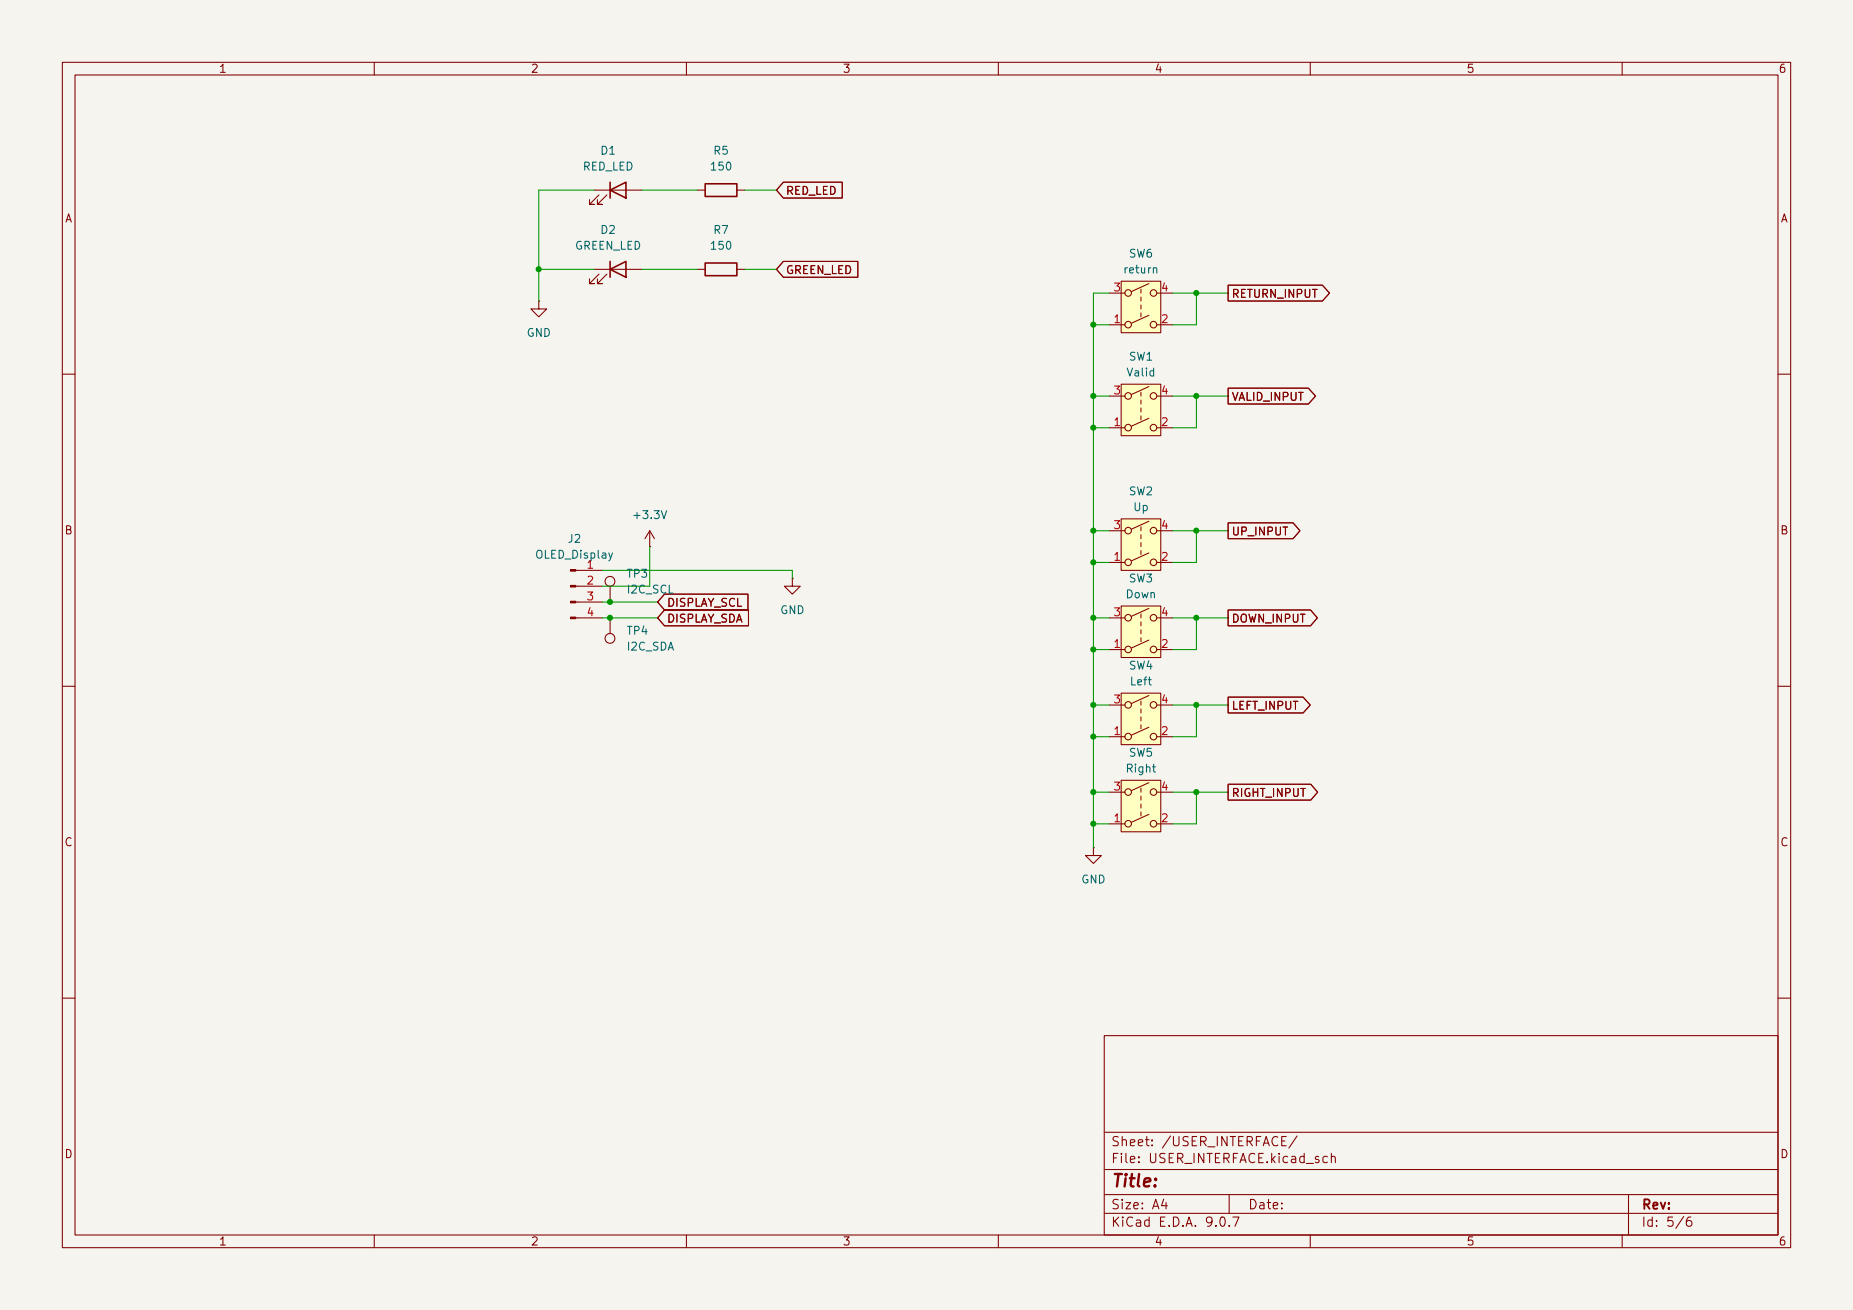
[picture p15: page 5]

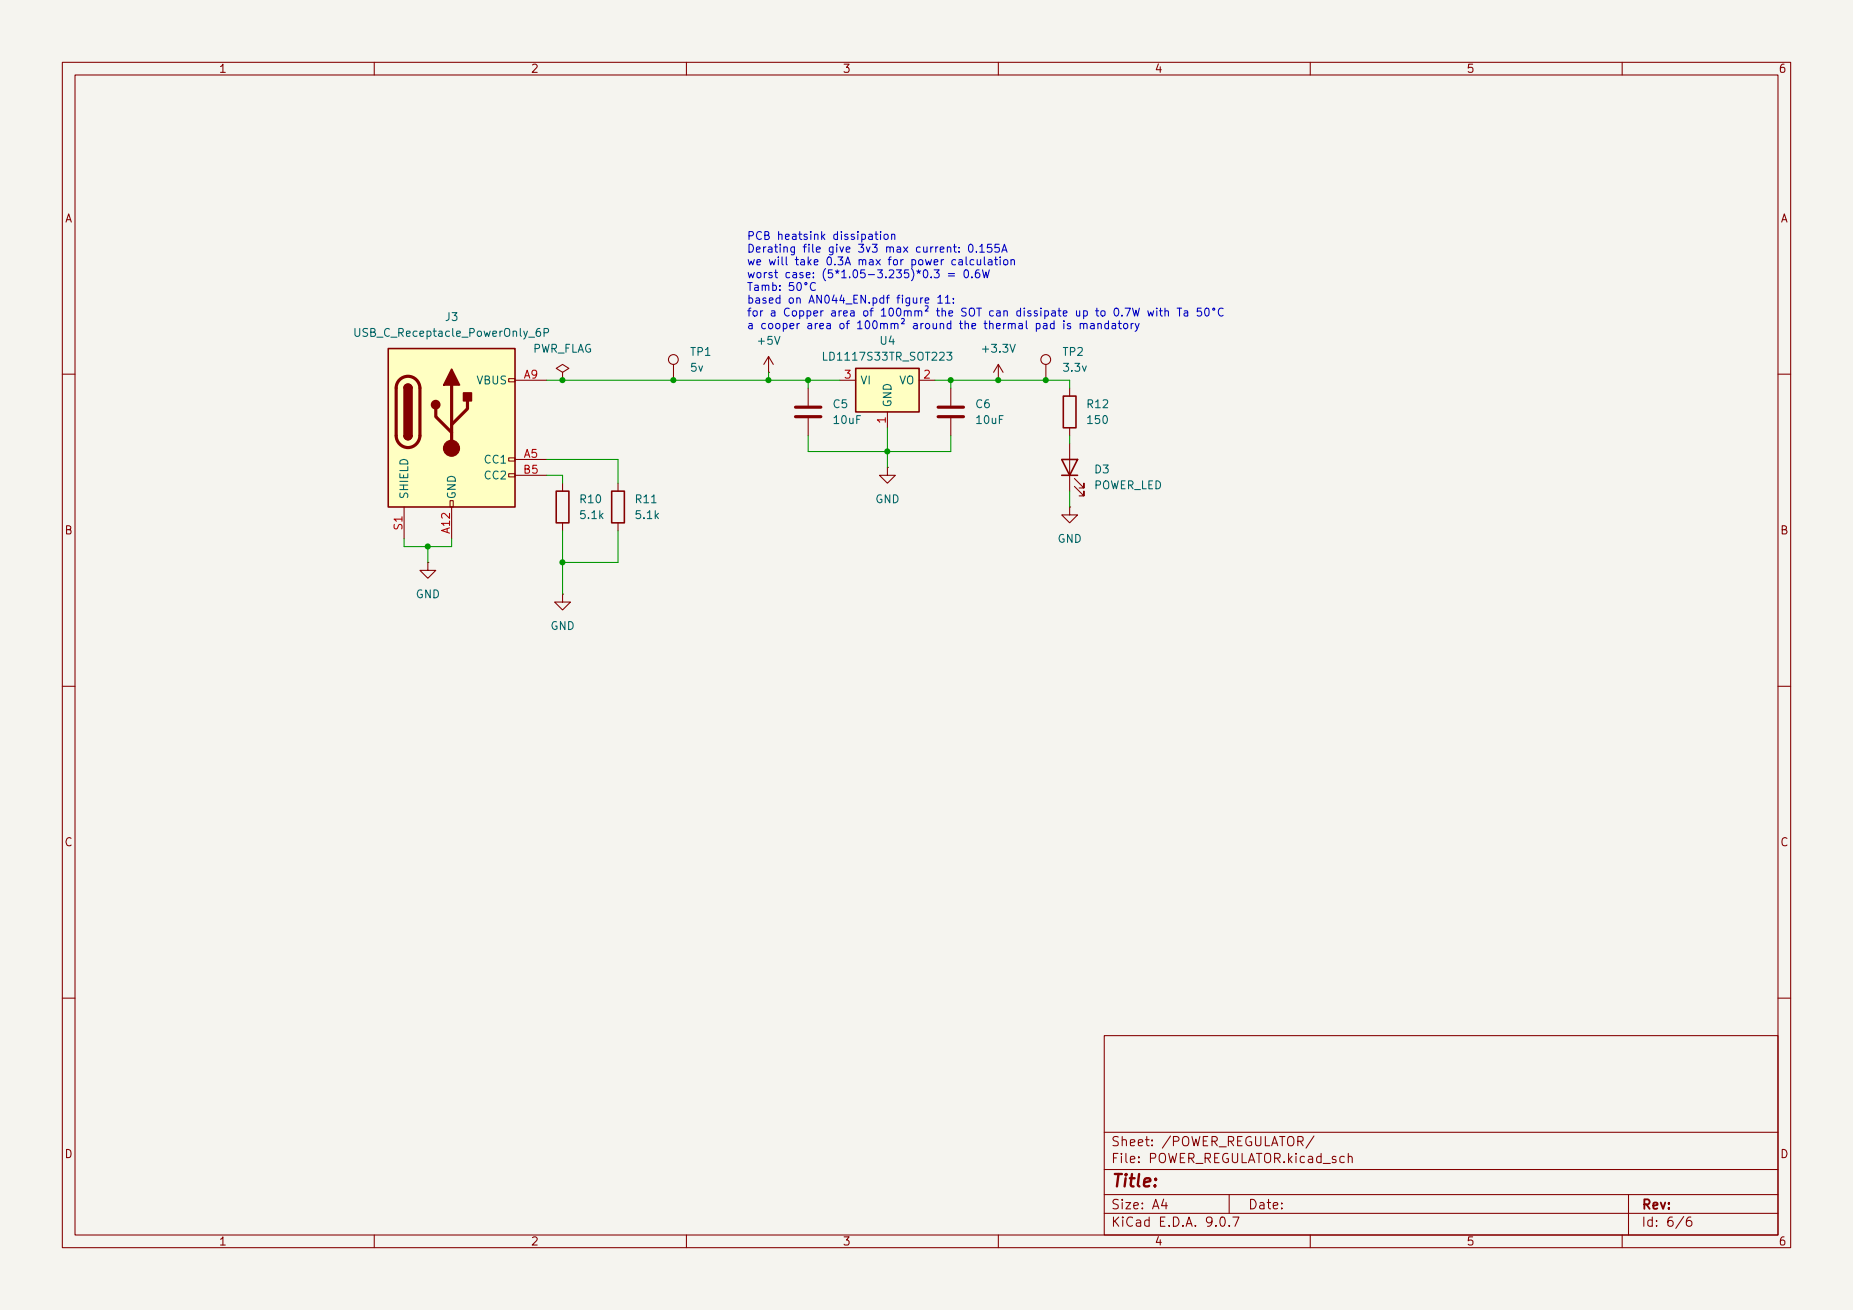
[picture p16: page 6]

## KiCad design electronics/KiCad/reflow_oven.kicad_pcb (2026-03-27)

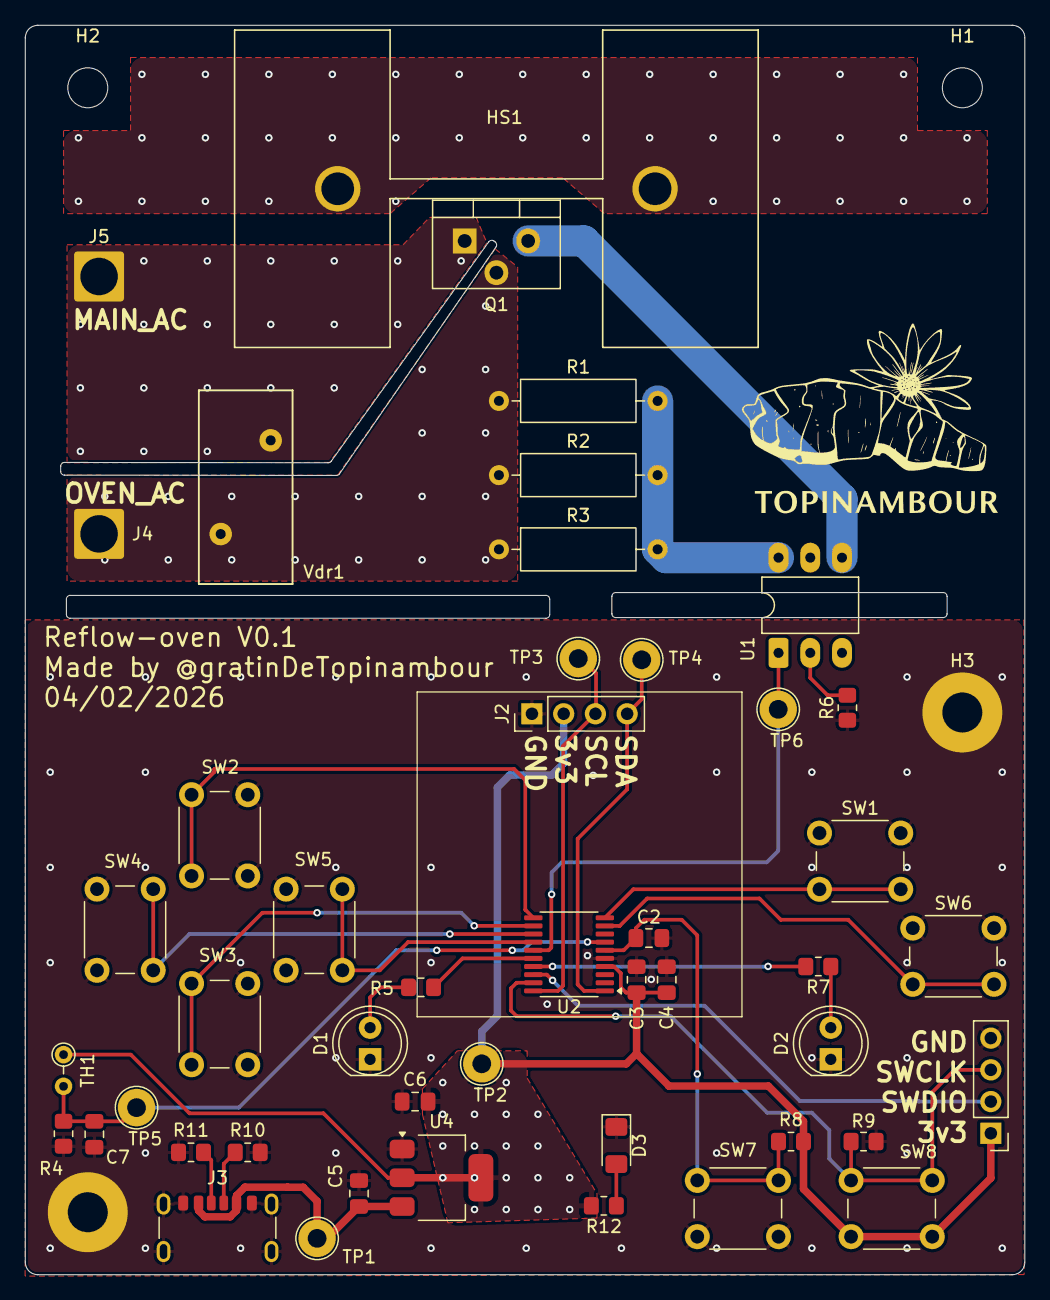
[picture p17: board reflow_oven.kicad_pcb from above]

Board: 2 copper layers, 80.0 x 100.0 mm, 51 parts (0 on the bottom side), 29 nets.

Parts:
C2, C3, C7: 100nF; C_0805_2012Metric_Pad1.18x1.45mm_HandSolder
C4: 4.7uF; C_0805_2012Metric_Pad1.18x1.45mm_HandSolder
C5, C6: 10uF; C_0805_2012Metric_Pad1.18x1.45mm_HandSolder
D1: RED_LED; LED_D5.0mm
D2: GREEN_LED; LED_D5.0mm
D3: POWER_LED; LED_1206_3216Metric_Pad1.42x1.75mm_HandSolder
H1, H2: MountingHole; MountingHole_3.2mm_M3
H3, H4: MountingHole_Pad; MountingHole_3.2mm_M3_Pad
HS1: Heatsink; HEATSINK_530002B02500G
J1: Conn_01x04_Pin; PinHeader_1x04_P2.54mm_Vertical
J2: OLED_Display; PinHeader_1x04_P2.54mm_Vertical
J3: USB_C_Receptacle_PowerOnly_6P; USB_C_Receptacle_GCT_USB4125-xx-x-0190_6P_TopMnt_Horizontal
J4: Load_AC; SolderWire-2.5sqmm_1x01_D2.4mm_OD3.6mm
J5: Main_AC; SolderWire-2.5sqmm_1x01_D2.4mm_OD3.6mm
Q1: BTA16-600CW; TO-220-3_Vertical
R1, R2, R3: 1100; R_Axial_DIN0309_L9.0mm_D3.2mm_P12.70mm_Horizontal
R4: 1800; R_0805_2012Metric_Pad1.20x1.40mm_HandSolder
R5, R6, R7, R12: 150; R_0805_2012Metric_Pad1.20x1.40mm_HandSolder
R8, R9: 10k; R_0805_2012Metric_Pad1.20x1.40mm_HandSolder
R10, R11: 5.1k; R_0805_2012Metric_Pad1.20x1.40mm_HandSolder
SW1: Valid; SW_PUSH_6mm_H5mm
SW2: Up; SW_PUSH_6mm_H5mm
SW3: Down; SW_PUSH_6mm_H5mm
SW4: Left; SW_PUSH_6mm_H5mm
SW5: Right; SW_PUSH_6mm_H5mm
SW6: return; SW_PUSH_6mm_H5mm
SW7: NRST; SW_PUSH_6mm_H5mm
SW8: BOOT0; SW_PUSH_6mm_H5mm
TH1: Thermistor_NTC; R_Axial_DIN0204_L3.6mm_D1.6mm_P2.54mm_Vertical
TP1: 5v; TestPoint_Loop_D2.54mm_Drill1.5mm_Beaded
TP2: 3.3v; TestPoint_Loop_D2.54mm_Drill1.5mm_Beaded
TP3: I2C_SCL; TestPoint_Loop_D2.54mm_Drill1.5mm_Beaded
TP4: I2C_SDA; TestPoint_Loop_D2.54mm_Drill1.5mm_Beaded
TP5: Temp; TestPoint_Loop_D2.54mm_Drill1.5mm_Beaded
TP6: Pwr_cmd; TestPoint_Loop_D2.54mm_Drill1.5mm_Beaded
U1: MOC3063M; DIP-6_W7.62mm_LongPads
U2: STM32C011F6Px; TSSOP-20_4.4x6.5mm_P0.65mm
U4: LD1117S33TR_SOT223; SOT-223-3_TabPin2
Vdr1: S14K230; RV_Disc_D15.5mm_W7.5mm_P7.5mm

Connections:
+3.3V: C3.1, C4.1, C6.1, J1.1, J2.2, R8.1, R12.2, SW8.1, TH1.1, TP2.1, U2.4 (VDD), U4.2 (VO)
+5V: C5.1, J3.A9 (VBUS), J3.B9 (VBUS), TP1.1, U4.3 (VI)
/MICRO_CONTROLLER/NRST: C2.1, R8.2, SW7.2, U2.6 (PF2)
/MICRO_CONTROLLER/SWCLK/Boot0: J1.3, R9.1, SW8.2, U2.19 (PA14)
/MICRO_CONTROLLER/SWDIO: J1.2, U2.18 (PA13)
DISPLAY_SCL: J2.3, TP3.1, U2.20 (PB6)
DISPLAY_SDA: J2.4, TP4.1, U2.1 (PB7)
DOWN_INPUT: SW3.2, U2.12 (PA5)
GND: C2.2, C3.2, C4.2, C5.2, C6.2, C7.2, D1.1 (K), D2.1 (K), D3.1 (K), H3.1, H4.1, J1.4, J2.1, J3.A12 (GND), J3.B12 (GND), J3.S1 (SHIELD), R4.2, R6.1, R9.2, R10.2, R11.2, SW1.1, SW2.1, SW3.1, SW4.1, SW5.1, SW6.1, SW7.1, U2.5 (VSS), U4.1 (GND)
GREEN_LED: R7.2, U2.17 (PA10/PA12)
LEFT_INPUT: SW4.2, U2.13 (PA6)
Load_AC: J4.1, Q1.2 (A2), R1.1, R2.1, R3.1, Vdr1.1
Main_AC: J5.1, Q1.1 (A1), Vdr1.2
unnamed: D1.2 (A), R5.1
unnamed: D2.2 (A), R7.1
unnamed: D3.2 (A), R12.1
unnamed: HS1.1, HS1.2
unnamed: J3.A5 (CC1), R11.1
unnamed: J3.B5 (CC2), R10.1
unnamed: Q1.3 (G), U1.4
unnamed: R1.2, R2.2, R3.2, U1.6
unnamed: R6.2, U1.2
Power_CMD: TP6.1, U1.1, U2.15 (PA8)
RED_LED: R5.2, U2.16 (PA9/PA11)
RETURN_INPUT: SW6.2, U2.9 (PA2)
RIGHT_INPUT: SW5.2, U2.14 (PA7)
TEMP_ANA: C7.1, R4.1, TH1.2, TP5.1, U2.7 (PA0)
UP_INPUT: SW2.2, U2.11 (PA4)
VALID_INPUT: SW1.2, U2.10 (PA3)

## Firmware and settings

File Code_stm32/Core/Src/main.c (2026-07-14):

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
/* Includes ------------------------------------------------------------------*/
#include "main.h"

/* USER CODE BEGIN Includes */
#include <string.h>
#include "OLED_096.h"
#include "NTC_thermistor.h"
#include "interface.h"
#include "OVEN_CTRL.h"
#include "app_state.h"
#include "EEPROM_EMUL.h"

/* USER CODE END Includes */

ADC_HandleTypeDef hadc1;

I2C_HandleTypeDef hi2c1;

/* USER CODE BEGIN PV */
extern uint8_t update_oled_screen;
extern uint8_t update_oled_menu;
extern Menu oled_menu;

extern TuneState tune_state;
extern CtrlState ctrl_state;
extern ReflowState reflow_state;

uint32_t now = 0;
uint32_t last_ctrl_time = 0;

AppContext app_ctx;

/* USER CODE END PV */

void SystemClock_Config(void);
static void MX_GPIO_Init(void);
static void MX_I2C1_Init(void);
static void MX_ADC1_Init(void);
/**
  * @brief  The application entry point.
  * @retval int
  */
int main(void)
{

  /* MCU Configuration--------------------------------------------------------*/

  /* Reset of all peripherals, Initializes the Flash interface and the Systick. */
  HAL_Init();

  /* Configure the system clock */
  SystemClock_Config();

  /* Initialize all configured peripherals */
  MX_GPIO_Init();
  MX_I2C1_Init();
  MX_ADC1_Init();
  /* USER CODE BEGIN 2 */

  HAL_ADCEx_Calibration_Start(&hadc1);
  //pwm start


  OLED_Init();
  EE_Read(app_ctx.settings);
  interface_init(&oled_menu);

  HAL_GPIO_WritePin(GPIOA, GPIO_PIN_11, GPIO_PIN_RESET); //RED LED
  HAL_GPIO_WritePin(GPIOA, GPIO_PIN_12, GPIO_PIN_RESET); //GREEN LED
  HAL_GPIO_WritePin(GPIOA, GPIO_PIN_8, GPIO_PIN_RESET); //OVEN

  /* USER CODE END 2 */

  /* Infinite loop */
  /* USER CODE BEGIN WHILE */
  while (1)
  {
	  now = HAL_GetTick();
	  app_ctx.current_time_ms = now;
	  app_ctx.current_temp_avg = (NTC_Read_Value(&hadc1) + NTC_Read_Value(&hadc1) + NTC_Read_Value(&hadc1)) / 3;

	  HAL_GPIO_WritePin(GPIOA, GPIO_PIN_12, (HAL_GetTick()/500)%2);

	  Button_Update(&oled_menu, &app_ctx);

	  if(now - last_ctrl_time >= 1000) //update time and temp each seconde
	  {
		  Time_Update((now - app_ctx.timer_start_ms)/1000);
		  Temp_Update(app_ctx.current_temp_avg);
		  SetPoint_Update(app_ctx.set_point);

		  if(app_ctx.system_state == STATE_AUTOTUNE)
		  {
			  TuneStep_Update(tune_state);
			  BangBangSetting_Update(app_ctx.settings[app_ctx.current_conf_index]);
			  OVEN_CTRL_AUTOTUNE(&app_ctx);
		  }
		  else if(app_ctx.system_state == STATE_REFLOW)
		  {
			  CtrlStep_Update(ctrl_state);
			  ReflowStep_Update(reflow_state);

			  OVEN_CTRL_REFLOW(&app_ctx);
			  OVEN_CTRL_CMD(&app_ctx);
			  if(reflow_state == REFLOW_DONE)
			  {
					oled_menu.cur_screen = oled_menu.next_screen;
					update_oled_menu = 1;
			  }
		  }
		  last_ctrl_time = now;
	  }

	  if (update_oled_screen) Update_Menu(&oled_menu);

	  if (update_oled_menu) Change_Menu(&oled_menu, &app_ctx);

	  HAL_Delay(10);
    /* USER CODE END WHILE */

    /* USER CODE BEGIN 3 */
  }
  /* USER CODE END 3 */
}

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


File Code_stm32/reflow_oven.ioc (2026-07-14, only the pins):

Mcu.UserName=STM32C011F6Px
PA0.Signal=ADC1_IN0
PA2.Signal=GPIO_Input
PA3.Signal=GPIO_Input
PA4.Signal=GPIO_Input
PA5.Signal=GPIO_Input
PA6.Signal=GPIO_Input
PA7.Signal=GPIO_Input
PA8.Signal=GPIO_Output
PB6.Signal=I2C1_SCL
PB7.Signal=I2C1_SDA

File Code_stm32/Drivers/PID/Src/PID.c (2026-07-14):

/*
 * PID.c
 *
 *  Created on: 13 févr. 2026
 *      Author: valentin
 */

#include "PID.h"

#define MAX_PWM 999

PIDSetting PID_set[6];

extern ADC_HandleTypeDef hadc1;
extern uint32_t PWM_data[1];
extern TIM_HandleTypeDef htim1;

int err_int; //integer error
int prev_err; //previous error

volatile int PWM_cycle = 0;

//SP set point
//PV process variable
//delta_t in ms
//return value between 0 and 100 (0% to 100% PWM)
int PID_PWM_cmd(int SP, int PV, uint32_t delta_t, PIDSetting *PID)
{
	int err = SP - PV;
	int cmd;

	//switch on oven until it reach 20°C error
	if(err > 20){
		PID->errint = 0;
		return 999;
	}

	//switch off oven if temp is 10°C higher than set point
	if(err < -10){
		return 0;
	}

	int err_drv = 1000*(err - prev_err)/delta_t;
	PID->errint += err*delta_t/1000;
	if(PID->errint  > 100) PID->errint  = 100;
	if(PID->errint  < -100) PID->errint  = -100;

	cmd = PID->Kp*err + PID->Ki*PID->errint  + PID->Kd*err_drv;

	prev_err = err;

	if(cmd > 999) cmd = 999;
	if(cmd < 0) cmd = 0;

	return cmd;
}

void PID_Init(void)
{
	for(uint8_t i = 0; i<6; i++)
	{
		PID_set[i].Kp = 999;
		PID_set[i].Ki = 0;
		PID_set[i].Kd = 0;
		PID_set[i].errint = 0;
	}
}

PIDSetting PID_AutoTune(uint16_t target_temp, uint32_t timeout)
{
	PIDSetting PID_auto;

	uint16_t current_temp = 0;
	uint32_t start_time = HAL_GetTick();
	uint32_t current_time = HAL_GetTick();

	uint8_t current_cycle = 0;
	uint8_t cycle_to_run = 3;
	uint16_t peak_max = 0;
	uint16_t peak_min = 1000;

	uint32_t t_start_cycle = 0;
	uint32_t t_period = 0;

	char temp[11];
	strcpy(temp, "T:");
	char max_temp[11];
	strcpy(max_temp, "max");
	char min_temp[11];
	strcpy(min_temp, "min");
	char cur_time[11];
	strcpy(cur_time, "time: ");
	char cycle[11];
	strcpy(cycle, "cycle: ");
	mini_sprintf(current_temp, temp + 2, 3);
	OLED_DrawString(temp, WHITE, 0, 15);
	mini_sprintf(peak_max, max_temp + 3, 3);
	OLED_DrawString(max_temp, WHITE, 42, 15);
	mini_sprintf(peak_min, min_temp + 3, 3);
	OLED_DrawString(min_temp, WHITE, 90, 15);

	mini_sprintf((current_time - start_time)/1000, cur_time + 6, 4);
	OLED_DrawString(cur_time, WHITE, 64-strlen(cur_time)*3, 30);
	mini_sprintf(current_cycle, cycle + 7, 1);
	OLED_DrawString(cycle, WHITE, 66, 45);
	OLED_UpdateScreen();

	PWM_data[0] = MAX_PWM;
	HAL_TIM_PWM_Start_DMA(&htim1, TIM_CHANNEL_1, PWM_data,1);

	while(current_temp <= target_temp && current_time < timeout + start_time)
	{
		mini_sprintf((current_time - start_time)/1000, cur_time + 6, 4);
		OLED_DrawString(cur_time, WHITE, 64-strlen(cur_time)*3, 30);
		mini_sprintf(current_temp, temp + 2, 3);
		OLED_DrawString(temp, WHITE, 0, 15);
		OLED_UpdateScreen();

		current_time = HAL_GetTick();
		current_temp = (NTC_Read_Value(&hadc1) + NTC_Read_Value(&hadc1) + NTC_Read_Value(&hadc1))/3;
		HAL_Delay(100);
	}
	mini_sprintf(current_temp, temp + 2, 3);
	OLED_DrawString(temp, WHITE, 0, 15);
	mini_sprintf(peak_max, max_temp + 3, 3);
	OLED_DrawString(max_temp, WHITE, 42, 15);
	mini_sprintf(peak_min, min_temp + 3, 3);
	OLED_DrawString(min_temp, WHITE, 90, 15);

	mini_sprintf((current_time - start_time)/1000, cur_time + 6, 4);
	OLED_DrawString(cur_time, WHITE, 64-strlen(cur_time)*3, 30);
	mini_sprintf(current_cycle, cycle + 7, 1);
	OLED_DrawString(cycle, WHITE, 66, 45);
	OLED_UpdateScreen();

	PWM_data[0] = 0;
	HAL_TIM_PWM_Start_DMA(&htim1, TIM_CHANNEL_1, PWM_data,1);

	while(current_temp >= target_temp && current_time < timeout + start_time)
	{
		mini_sprintf((current_time - start_time)/1000, cur_time + 6, 4);
		OLED_DrawString(cur_time, WHITE, 64-strlen(cur_time)*3, 30);
		mini_sprintf(current_temp, temp + 2, 3);
		OLED_DrawString(temp, WHITE, 0, 15);
		OLED_UpdateScreen();

		current_time = HAL_GetTick();
		current_temp = (NTC_Read_Value(&hadc1) + NTC_Read_Value(&hadc1) + NTC_Read_Value(&hadc1))/3;

		if (current_temp > peak_max)
		{
			peak_max = current_temp;
			mini_sprintf(peak_max, max_temp + 3, 3);
			OLED_DrawString(max_temp, WHITE, 42, 15);
		}
		if (current_temp < peak_min)
		{
			peak_min = current_temp;
			mini_sprintf(peak_min, min_temp + 3, 3);
			OLED_DrawString(min_temp, WHITE, 90, 15);
		}
		HAL_Delay(100);

	}
	mini_sprintf(current_temp, temp + 2, 3);
	OLED_DrawString(temp, WHITE, 0, 15);
	mini_sprintf(peak_max, max_temp + 3, 3);
	OLED_DrawString(max_temp, WHITE, 42, 15);
	mini_sprintf(peak_min, min_temp + 3, 3);
	OLED_DrawString(min_temp, WHITE, 90, 15);

	mini_sprintf((current_time - start_time)/1000, cur_time + 6, 4);
	OLED_DrawString(cur_time, WHITE, 64-strlen(cur_time)*3, 30);
	mini_sprintf(current_cycle, cycle + 7, 1);
	OLED_DrawString(cycle, WHITE, 66, 45);
	OLED_UpdateScreen();

	PWM_data[0] = MAX_PWM;

	while(current_cycle < cycle_to_run && current_time < timeout + start_time)
	{
		mini_sprintf((current_time - start_time)/1000, cur_time + 6, 4);
		OLED_DrawString(cur_time, WHITE, 64-strlen(cur_time)*3, 30);
		mini_sprintf(current_temp, temp + 2, 3);
		OLED_DrawString(temp, WHITE, 0, 15);
		OLED_UpdateScreen();

		current_time = HAL_GetTick();
		current_temp = (NTC_Read_Value(&hadc1) + NTC_Read_Value(&hadc1) + NTC_Read_Value(&hadc1))/3;
		if(current_temp > target_temp && PWM_data[0] == MAX_PWM)
		{
			PWM_data[0] = 0;

			if (t_start_cycle != 0) {
				t_period += (HAL_GetTick() - t_start_cycle);
				current_cycle++;
			}
			t_start_cycle = HAL_GetTick();
			mini_sprintf(current_cycle, cycle + 7, 1);
			OLED_DrawString(cycle, WHITE, 66, 45);
		}
		else if(current_temp < target_temp && PWM_data[0] == 0)
		{
			PWM_data[0] = MAX_PWM;
		}

		if (current_temp > peak_max)
		{
			peak_max = current_temp;
			mini_sprintf(peak_max, max_temp + 3, 3);
			OLED_DrawString(max_temp, WHITE, 42, 15);
		}
		if (current_temp < peak_min)
		{
			peak_min = current_temp;
			mini_sprintf(peak_min, min_temp + 3, 3);
			OLED_DrawString(min_temp, WHITE, 90, 15);
		}
		HAL_Delay(100);
	}

	PWM_data[0] = 0;

	t_period = t_period/cycle_to_run;

	//Åström-Hägglund method

	float ampl = (peak_max - peak_min)/2;
	float Ku = (4.0f * MAX_PWM) / (3.14f * ampl);
	float Tu = t_period/1000.0;

	//Ziegler–Nichols method for PI
	PID_auto.Kp = 0.45*Ku;
	PID_auto.Ki = 0.54*Ku/Tu;
	PID_auto.Kd = 0;
	HAL_TIM_PWM_Stop_DMA(&htim1, TIM_CHANNEL_1);

	return PID_auto;
}


void HAL_TIM_PWM_PulseFinishedCallback(TIM_HandleTypeDef *htim)
{
  PWM_cycle++;
}

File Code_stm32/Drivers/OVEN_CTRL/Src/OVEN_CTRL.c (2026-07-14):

/*
 * OVEN_CTRL.c
 *
 *  Created on: 20 févr. 2026
 *      Author: valentin
 */
#include "OVEN_CTRL.h"
#include "NTC_thermistor.h"

extern ADC_HandleTypeDef hadc1;

TuneState tune_state = TUNE_IDLE;
CtrlState ctrl_state = CTRL_IDLE;
ReflowState reflow_state = REFLOW_IDLE;

#define SN42BI58 {100, 90, 138, 100, 170, 60}
#define SAC305 {0, 0, 0, 0, 0, 0}
#define SN63PB37 {0, 0, 0, 0, 0, 0}
#define MANUAL {0, 0, 0, 0, 0, 0}
ReflowSetting RS[4] = {SN42BI58, SAC305, SN63PB37, MANUAL};

uint16_t tune_temp_initial = 0;
uint16_t tune_temp_peak = 0;
uint16_t tune_temp_slope_start = 0;
uint16_t tune_temp_cutoff = 0;
uint32_t tune_t_start = 0;
uint32_t tune_t_slope_start = 0;
uint8_t  tune_cooling_count = 0;

uint32_t ctrl_timeout = 600000;
uint32_t ctrl_start_timer = 0;
uint32_t ctrl_heat_start_timer = 0;
uint16_t ctrl_start_temp = 0;
uint16_t ctrl_predicted_temp = 0;
uint32_t ctrl_heat_timer = 0;
int ctrl_pred_heat_timer = 0;
uint8_t ctrl_temp_increase = 0;
uint16_t ctrl_temp_rise = 0;
uint8_t ctrl_L_update = 0;
uint16_t peak_temp_value = 0;

uint32_t reflow_timer_start = 0;
uint32_t reflow_timer_soak = 0;
uint16_t reflow_peak_temp = 0;
uint32_t reflow_peak_time = 0;




void OVEN_CTRL_AUTOTUNE(AppContext *ctx)
{
	switch (tune_state)
	{
	case TUNE_IDLE:
		break;

	case TUNE_START:
		ctx->timer_start_ms = ctx->current_time_ms;
		tune_temp_initial = ctx->current_temp_avg;
		tune_t_start = ctx->current_time_ms;

		HAL_GPIO_WritePin(GPIOA, OVEN, GPIO_PIN_SET);
		HAL_GPIO_WritePin(GPIOA, RED_LED, GPIO_PIN_SET);

		tune_state = TUNE_MEASURE_LAG;
		break;

	case TUNE_MEASURE_LAG:
		// Wait for +2°C rise
		if (ctx->current_temp_avg >= tune_temp_initial + 2)
		{
			// Calculate L
			ctx->settings[ctx->current_conf_index].L = (ctx->current_time_ms - tune_t_start) / 1000;


			// Prepare next step
			tune_t_slope_start = ctx->current_time_ms;
			tune_temp_slope_start = ctx->current_temp_avg;
			tune_state = TUNE_MEASURE_SLOPE;
		}
		break;

	case TUNE_MEASURE_SLOPE:
		// Wait for 80% of target
		if (ctx->current_temp_avg >= (ctx->set_point * 8 / 10))
		{
			uint32_t t_slope_end = ctx->current_time_ms;

			// Calculate v (Prevent division by zero)
			uint32_t duration_sec = (t_slope_end - tune_t_slope_start) / 1000;
			if(duration_sec == 0) duration_sec = 1;

			ctx->settings[ctx->current_conf_index].v = 100 * (ctx->current_temp_avg - tune_temp_slope_start) / duration_sec;

			HAL_GPIO_WritePin(GPIOA, OVEN, GPIO_PIN_RESET); // OVEN OFF
			HAL_GPIO_WritePin(GPIOA, RED_LED, GPIO_PIN_RESET);

			tune_temp_cutoff = ctx->current_temp_avg;
			tune_temp_peak = ctx->current_temp_avg;
			tune_cooling_count = 0;

			tune_state = TUNE_COOLING;
		}
		break;

	case TUNE_COOLING:

		if (ctx->current_temp_avg > tune_temp_peak)
		{
			tune_temp_peak = ctx->current_temp_avg;
			tune_cooling_count = 0; // Reset counter if temp still rising
		}
		else
		{
			tune_cooling_count++;
		}

		// If temp hasn't risen for 10 seconds
		if (tune_cooling_count >= 20)
		{
			ctx->settings[ctx->current_conf_index].overshoot = 100*(tune_temp_peak - tune_temp_initial)/(tune_temp_cutoff - tune_temp_initial) - 100;
			tune_state = TUNE_DONE;
		}
		break;

	case TUNE_DONE:
		// Tuning complete
		HAL_GPIO_WritePin(GPIOA, OVEN, GPIO_PIN_RESET); // Ensure OFF
		HAL_GPIO_WritePin(GPIOA, RED_LED, GPIO_PIN_RESET);
		tune_state = TUNE_IDLE; // Reset FSM
		break;

	default:
		HAL_GPIO_WritePin(GPIOA, OVEN, GPIO_PIN_RESET); // Ensure OFF
		HAL_GPIO_WritePin(GPIOA, RED_LED, GPIO_PIN_RESET);
		tune_state = TUNE_IDLE; // Reset FSM
		break;
	}
}

void OVEN_CTRL_CMD(AppContext *ctx)
{
	uint16_t slope = (ctx->settings[ctx->current_conf_index].v == 0) ? 1 : ctx->settings[ctx->current_conf_index].v;
	uint32_t lag_ms = ctx->settings[ctx->current_conf_index].L * 1000;


	switch(ctrl_state)
	{
	case CTRL_IDLE:
		break;
	case CTRL_START:
		ctrl_start_timer = ctx->current_time_ms;
		ctrl_heat_start_timer = ctx->current_time_ms;
		ctrl_temp_rise = (ctx->set_point - ctx->current_temp_avg);
		ctrl_pred_heat_timer = 0;
		ctrl_start_temp = ctx->current_temp_avg;
		ctrl_L_update = 1;
		if(ctrl_heat_timer -  ctrl_heat_start_timer> 0)
		{
			if(ctrl_temp_rise > 20)
			{
				ctrl_state = CTRL_FAST_HEAT;
			}
			else
			{
				ctrl_heat_timer = ctrl_heat_start_timer + 1000*100*(ctrl_temp_rise)/slope;
				ctrl_state = CTRL_HEAT;
			}
			HAL_GPIO_WritePin(GPIOA, OVEN, GPIO_PIN_SET);
			HAL_GPIO_WritePin(GPIOA, RED_LED, GPIO_PIN_SET);
		}
		else
		{
			ctrl_state = CTRL_COOL;
			HAL_GPIO_WritePin(GPIOA, OVEN, GPIO_PIN_RESET);
			HAL_GPIO_WritePin(GPIOA, RED_LED, GPIO_PIN_RESET);
		}
		break;

	case CTRL_HEAT:
		uint32_t heat_time = ctx->current_time_ms - ctrl_heat_start_timer;
		if (ctx->current_temp_avg > ctrl_start_temp + 1 && ctrl_L_update)
		{
			ctx->settings[ctx->current_conf_index].L = heat_time/1000;
			ctrl_L_update = 0;
		}

		if(heat_time > lag_ms)
		{
			ctrl_predicted_temp = ctrl_start_temp + (heat_time - lag_ms)*slope/(100*1000);
			ctrl_pred_heat_timer = 1000*100*(ctrl_predicted_temp - ctx->current_temp_avg)/slope;
		}
		else
		{
			ctrl_predicted_temp = ctrl_start_temp;
			ctrl_pred_heat_timer = 1000*100*(ctrl_predicted_temp - ctx->current_temp_avg)/slope;
		}

		if(ctx->current_temp_avg > ctx->set_point || ctx->current_time_ms >= ctrl_heat_timer + ctrl_pred_heat_timer)
		{
			ctrl_state = CTRL_COOL;
			HAL_GPIO_WritePin(GPIOA, OVEN, GPIO_PIN_RESET);
			HAL_GPIO_WritePin(GPIOA, RED_LED, GPIO_PIN_RESET);
			peak_temp_value = ctx->current_temp_avg;
			ctrl_temp_increase = 0;
		}

		if(ctx->current_time_ms - ctrl_start_timer > ctrl_timeout)
		{
			ctrl_state = CTRL_DONE;
		}
		break;

	case CTRL_FAST_HEAT:
		if (ctx->current_temp_avg > ctrl_start_temp + 1 && ctrl_L_update)
		{
			ctx->settings[ctx->current_conf_index].L = (ctx->current_time_ms - ctrl_heat_start_timer)/1000;
			ctrl_L_update = 0;
		}

		if((ctx->current_time_ms - ctrl_heat_start_timer) > lag_ms)
		{
			ctrl_predicted_temp = ctrl_start_temp + ((ctx->current_time_ms - ctrl_heat_start_timer) - lag_ms)*slope/(100*1000);
			ctrl_pred_heat_timer = 1000*100*(ctrl_predicted_temp - ctx->current_temp_avg)/slope;
		}
		else
		{
			ctrl_predicted_temp = ctrl_start_temp;
			ctrl_pred_heat_timer = 1000*100*(ctrl_predicted_temp - ctx->current_temp_avg)/slope;
		}

		if(ctx->current_temp_avg > (ctrl_start_temp + ctrl_temp_rise*(100-ctx->settings[ctx->current_conf_index].overshoot)/100))
		{
			ctrl_state = CTRL_COOL;
			HAL_GPIO_WritePin(GPIOA, OVEN, GPIO_PIN_RESET);
			HAL_GPIO_WritePin(GPIOA, RED_LED, GPIO_PIN_RESET);
			peak_temp_value = ctx->current_temp_avg;
			ctrl_temp_increase = 0;
		}

		if(ctx->current_time_ms - ctrl_start_timer > ctrl_timeout)
		{
			ctrl_state = CTRL_DONE;
		}
		break;

	case CTRL_COOL:
		if(ctx->current_temp_avg > peak_temp_value)
		{
			peak_temp_value = ctx->current_temp_avg;
			ctrl_temp_increase = 0;
		}
		else
		{
			ctrl_temp_increase++;
		}
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

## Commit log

2026-07-14 Add files via upload
    adding code for stm32
2026-07-14 Add files via upload
    adding drivers

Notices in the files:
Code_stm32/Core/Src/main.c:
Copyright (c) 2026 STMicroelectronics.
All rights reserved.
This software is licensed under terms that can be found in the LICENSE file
